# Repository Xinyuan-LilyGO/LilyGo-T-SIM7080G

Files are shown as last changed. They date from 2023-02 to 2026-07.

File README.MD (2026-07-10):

<h1 align = "center">✨ LilyGO T-SIM7080G  ✨</h1>

## **English | [中文](README_CN.MD)**

## News

- SIM7080G supports **NB-IoT** and **Cat-M** in global frequency bands, but does **not support 2G/3G/4G**. Please confirm that the SIM card used supports **NB-IoT** or **Cat-M** before use.
- The SIM card must be inserted first before starting the SIM7080. If the SIM card is inserted after the SIM7080 is turned on, the modem will not be able to detect the SIM card.

## 1️⃣ Examples preview

```
examples 
├─AllFunction                       # Full function test example
├─ATDebug                           # AT Commands Example
├─BIGIOT_Gnss_Upload                # Upload positioning coordinates to BIGIOT IOT,Timed wake-up consumes about 1.2mA
├─BLE5_extended_scan                # Official BLE5 Example
├─BLE5_multi_advertising            # Official BLE5 Example
├─BLE5_periodic_advertising         # Official BLE5 Example    
├─BLE5_periodic_sync                # Official BLE5 Example
├─MinimalCameraExample              # Example of camera use
├─MinimalDeepSleepExample           # DeepSleep example
├─MinimalLowBattPowerExample        # Low Battery example
├─MinimalModemGPSExample            # SIM7080G GPS example
├─MinimalModemNBIOTExample          # SIM7080G NBIOT example
├─MinimalModemPowerSaveMode         # SIM7080G power maintenance example
├─MinimalModemSleepMode             # SIM7080G sleep example
├─MinimalModemAndEspSleep           # SIM7080G & ESP32 sleep example
├─MinimalModemUpgrade               # Upgrade SIM7080 built-in firmware
├─MinimalPowersCurrentExample       # Example of PMU charge current debug
├─MinimalPowersExample              # Example of PMU
├─MinimalSDCardExample              # Example of using SDCard
├─ModemFileUploadExample            # File Upload Example            
├─ModemMqttPublishExample           # MQTT Publish Example            
├─ModemMqttsAuthExample             # MQTTS Authentication Example    
├─ModemMqttsExample                 # MQTTS Example    
├─ModemMqttSubscribeExample         # MQTT Subscribe Example     
├─SIM7080G-ATT-NB-IOT-AWS-MQTT      # MQTTS AWS By @bootcampiot
├─SIM7080G-ATT-NB-IOT-HTTP-HTTPS    # HTTP/HTTPS  By @bootcampiot
└─SIM7080G-ATT-NB-IOT-SSL-Mosquitto # MQTTS Mosquitto By @bootcampiot
```

## 2️⃣ Quick Start

### PlatformIO

1. Install [VisualStudioCode](https://code.visualstudio.com/) and [Python](https://www.python.org/)
2. Search for the `PlatformIO` plugin in the `VisualStudioCode` extension and install it.
3. After the installation is complete, you need to restart `VisualStudioCode`
4. After restarting `VisualStudioCode`, select `File` in the upper left corner of `VisualStudioCode` -> `Open Folder` -> select the `LilyGo-T-SIM7080G` directory
5. Click on the `platformio.ini` file, and in the `platformio` column, cancel the sample line that needs to be used, please make sure that only one line is valid
6. Click the (✔) symbol in the lower left corner to compile
7. Connect the board to the computer USB
8. Click (→) to upload firmware
9. Click (plug symbol) to monitor serial output

### ArduinoIDE

1. Install [ArduinoIDE](https://www.arduino.cc/en/software)
2. Copy all the folders in the `LilyGo-T-SIM7080G/lib` directory to `<C:\Users\UserName\Documents\Arduino\libraries>`. If there is no `libraries` directory, please create a new one. Please note that you are not copying the `lib` directory, but copying the folders in the lib directory
3. Open Arduino IDE -> Tools
- Board -> ESP32S3 Dev Module
- USB CDC On Boot -> Enable  ## Note that you need to change Enable to Disable when USB is not connected, so USB CDC will not prevent the board from starting
- CPU Frequency -> 240MHz
- USB DFU On Boot -> Disable
- Flash Mode -> QIO 80MHz
- Flash Size -> 16MB(128Mb)
- USB Firmware MSC On Boot -> Disable
- PSRAM -> OPI PSRAM
- Partition Scheme -> 16M Flash(3MB APP/9.9MB FATFS)
- USB Mode -> Hardware CDC and JTAG
- Upload Mode -> UART0/Hardware CDC
- Upload Speed -> 921600
4. Insert USB into the PC and click Upload <If the upload fails, see Tips>

### Use reference

| Product | Youtube  link | explanation | Status | 
| :---: | :---: |:---:| :----: |
| T -7080G | [Youtube link](https://www.youtube.com/watch?v=lGctqLDGHz4) | How to update the firmware of SIM7080G series products | ✅ |
| LilyGo device | [Youtube link](https://www.youtube.com/watch?v=f3BybP3L7ls) | How to enter boot mode to download the firmware | ✅ |

## 3️⃣ Tips

0. T-SIM7080 has two USB ports, the USB-C port is used to upload sketches and Serial output, and Micro-USB is used for SIM7080G firmware version upgrade
1. ⚠ SIM7080G cannot connect to cellular network and GPS positioning at the same time
2. Board integrated PMU (Power management chip), with short circuit and overload protection. By default,`PWRKEY`needs to be pressed for 6 seconds to turn off the board power supply, and press`PWRKEY`for 128 milliseconds to turn on the power supply. If you need to modify the power off pressing time, please refer to`MinimalPowersExample`
3. If the charging function is required, the`PMU` `TS Pin`detection function needs to be turned off. By default, there is no NTC sensor on the board, so the `TS Pin` detection needs to be disabled before the charging function can be used normally. If the`TS Pin`detection function is not turned off, the PMU charging indicator will flash after the battery is inserted, and charging will be disabled
4. The VSYS pin is the system path voltage of the PMU. The voltage of this pin is equal to the input voltage. The output of this pin is equal to the input voltage. If the input voltage source is USB-C, then this pin is the voltage of USB-C. If it is a battery, then this pin is the voltage of the battery.
5. The `DC5` power supply voltage can be adjusted, and the maximum output current should not exceed `1A`
6. `DC1` is the core power supply voltage, and the default output is `3.3V`. Please do not adjust the `DC1` voltage through software
7. When the sketch cannot be uploaded, please press and hold the `BOOT` button on the board, and then insert the USB. At this time, you should be able to see the port in the device manager of the computer, and then click Upload Sketch again
8. When the power supply channel of the `ESP32S3` is closed incorrectly, please insert USB, and then press and hold the `BOOT` button of the board, and then press and hold the `PWRKEY` button. At this time, the board enters the download mode, and the sketch can be uploaded normally
9. If the power supply of the board cannot be turned on when the battery is connected, please check that the mechanical switch beside the USB is turned to`ON`, and then press the board `PWR` for `2 seconds`. At this time, the board should start to work
10. The range of solar input voltage is `4.4~6V`. Please select an appropriate solar panel and set the maximum charging current as `500mA`
11. If the camera is not connected, all IO ports are available. If the camera is used, the board has only `GPIO45` and `GPIO46` is idle
12. `T-SIM7080G` uses `Octal SPI PSRAM`, so **GPIO35~GPIO37** is unavailable. Please do not use these IOs
13. ⚠ **Please understand the risks to be faced before changing the voltage of peripherals, otherwise do not try to change the voltage of cameras and other on-board devices, which may cause permanent damage**
14. ⚠ **Please do not turn off the BLDO1 power supply, otherwise ESP32S3 and SIM7080G cannot communicate normally**
15. Please check the [Operating Instructions](./docs/sim7080_update_firmware.md) for updating the built-in firmware of the modem. Generally, upgrading the firmware is not recommended
16. The board uses USB as the JTAG upload port. When printing serial port information on USB_CDC_ON_BOOT configuration needs to be turned on. 
If the port cannot be found when uploading the program or the USB has been used for other functions, the port does not appear. 
Please enter the upload mode manually. 
    1. Connect the board via the USB cable
    2. Press and hold the BOOT button , While still pressing the BOOT button, press RST
    3. Release the RST
    4. Release the BOOT button
    5. Upload sketch
17. If you encounter a problem that you cannot register a network, please refer to this [issue#100](https://github.com/Xinyuan-LilyGO/LilyGo-T-SIM7080G/issues/100#issuecomment-2662392543)
18. How to connect an external 5V circuit to the board?
    1. The SIM7080G-PMU version does not have a pre-installed 5V external pin. If you need to connect an external 5V source but don't want to use a USB-C connection, you can solder the external 5V positive terminal to the pad as shown in the diagram below.
    

## 4️⃣ Where to buy:

1. [AliExpress](https://www.aliexpress.us/item/3256805002673427.html)
2. [LilyGo Store](https://www.lilygo.cc/products/t-sim7080-s3)

## 5️⃣ Pins

| Camera | PWDN | Reset  | XCLK | SDA | SCL | VSYNC  | HREF | PCLK |
| --- | --- | --- | --- | --- | --- | --- | --- | --- |
| GPIO | N/A | 18 | 8 | 2 | 1 | 16 | 17 | 12 |
| **Camera** | **D9** | **D8** | **D7** | **D6** | **D5** | **D4** | **D3** | **D2** |
| GPIO | 9 | 10 | 11 | 13 | 21 | 48 | 47 | 14 |

* If you do not use a camera, you can freely allocate IO ports here. Assuming you need to allocate I2C, please use the display to call Wire and pass the required IO ports, such as
    ```c
    int sda = 13;  // You can also use other IO ports
    int scl = 21;  // You can also use other IO ports
    Wire.begin(sda,scl)
    ```

| Modem | PWR | RXD | TXD | RI  | DTR |
| ----- | --- | --- | --- | --- | --- |
| GPIO  | 41  | 4 | 5 | 3 | 42  |

| PMU  | SDA | SCL | IRQ |
| ---- | --- | --- | --- |
| GPIO | 15  | 7 | 6 |

| SDCard | CMD | CLK | DATA |
| --- | --- | --- | ---- |
| GPIO | 39  | 38  | 40 |

## 6️⃣ Power domain

| Modem | Camera | ESP32S3 | SDCard | Level conversion |
| --- | --- | --- | --- | --- |
| DC3/BLDO2(GPS) | ALDO1/ALDO2/ALDO4 | DC1 | ALDO3  | BLDO1 |

## 7️⃣ Voltage range

| Battery Voltage requirements | Minimum | Maximum | Charging Current |
| --- | --- | --- | --- |
| SIM7080G | 3.5V | 4.2V | Custom adjustment, maximum 1A |

* It is recommended to use flat top 18650 batteries with a capacity of more than 2500mA

| Solar Voltage requirements | Minimum | Maximum | Charging Current |
| --- | --- | --- | --- |
| SIM7080G | 4.4V | 6V | 500mA |

> \[!TIP]
>
> It is recommended to use a solar panel with an output voltage of 6V or 5V and a power of about 5-10W. Solar energy can only charge the battery. Without the battery, the panel cannot supply power.
> Please note that this is only a suggestion. It is not necessary to use a 5-10W solar panel. 1W is also acceptable.
> The size of the solar panel determines the current and speed of solar charging. Please note that depending on the environment,
> the sunshine time may not exceed one hour per day. At this time, if the solar panel is too small and the light is not sufficient, it cannot be charged.

## 8️⃣ ON-BOARD LED

| FUNCTION | COLOR |
| --- | --- |
| MODEM STATUS | RED (Near the modem) |
| MODEM NETWORK STATE | RED (Near the modem) |
| CHARGE LED | BLUE (Controlled by PMU, default charging indicator) |

* The network status light can be turned off by command, please see the AT manual `AT+CNETLIGHT` command
* Status light cannot be turned off

### **MODEM NETWORK STATE**

| Network light status | Module working status |
| --- | --- |
| 64ms on/ 800ms off | When not registered on the network |
| 64ms on/ 3000ms off  | Already registered on the network (PS domain registration successful) |
| 64ms on/ 300ms off | During data transmission (PPP dial-up state and when using internal TCP/FTP/HTTP and other data services) |
| Off | Power off or PSM sleep mode |

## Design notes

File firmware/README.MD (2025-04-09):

## 1. News

* The firmware supports any one in the list below. The firmware used in the list below is the same and there is no need to distinguish it.

## 2. How to Flash ?

### Use ESP Download Tool

- Download [Flash_download_tool](https://www.espressif.com.cn/sites/default/files/tools/flash_download_tool_3.9.7_0.zip)

web_flasher

* Note that after writing is completed, you need to press RST to reset.

### Use Web Flasher

- [ESP Web Flasher Online](https://espressif.github.io/esptool-js/)

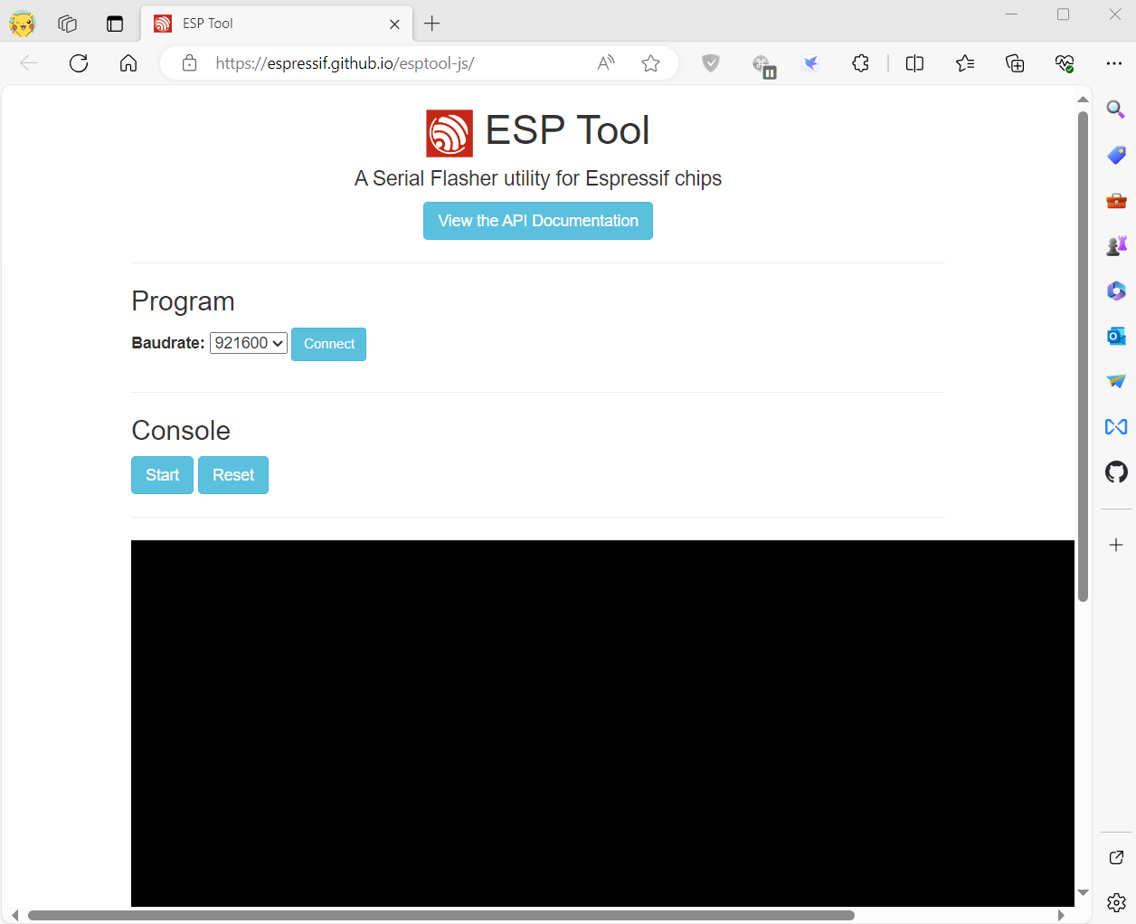
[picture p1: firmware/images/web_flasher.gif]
web_flasher


* Note that after writing is completed, you need to press RST to reset.

### Use command line

If system asks about install Developer Tools, do it.

```bash
python3 -m pip install --upgrade pip
python3 -m pip install esptool
```

In order to launch esptool.py, exec directly with this:

```bash
python3 -m esptool
```

```bash
esptool --chip esp32s3 --baud 921600 --before default_reset --after hard_reset write_flash -z --flash_mode dio --flash_freq 80m 0x0 firmware_file.bin
```

## 3. FAQ

Can't upload any sketch, please enter the upload mode manually.

1. Connect the board via the USB cable
2. Press and hold the **BOOT** button, While still pressing the **BOOT** button, **Not SBOOT**
3. Press **RST** button
4. Release the **RST** button
5. Release the **BOOT** button
6. Upload sketch
7. Press the **RST** button to exit download mode

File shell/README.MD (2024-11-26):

## A76XX-3D.stp

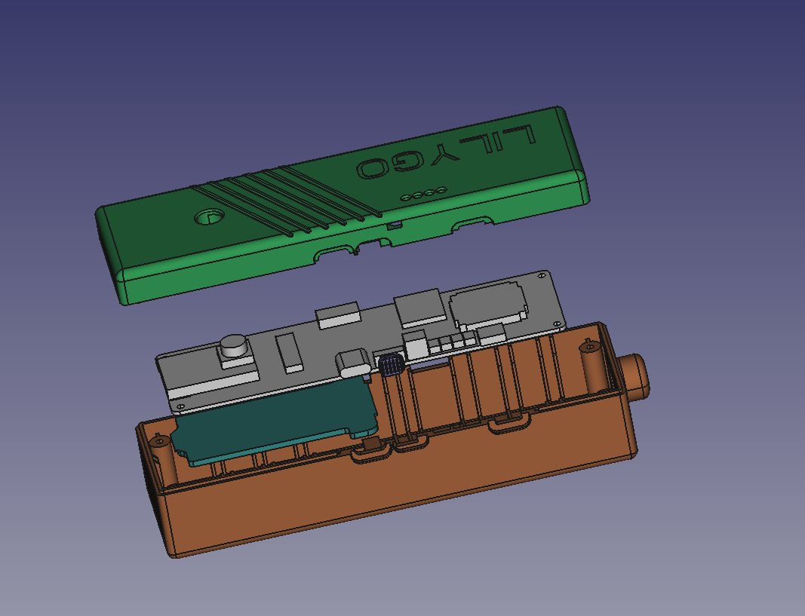
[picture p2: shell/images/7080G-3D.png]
A76XX-3D.stp


# Battery Holder

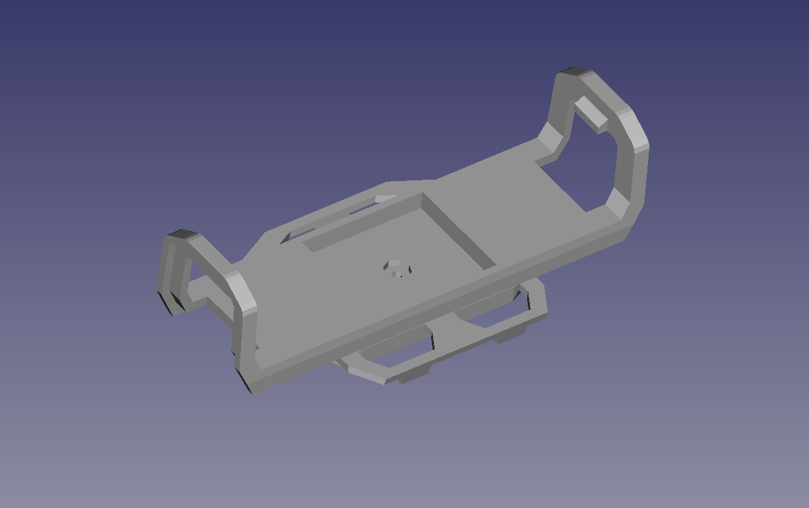
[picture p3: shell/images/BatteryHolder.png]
BatteryHolder


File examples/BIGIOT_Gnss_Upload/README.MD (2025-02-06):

[Platform link](https://www.bigiot.net)
[Relevant communication protocol of Shell IOT users](https://www.bigiot.net/help/33.html)

## Current consumption

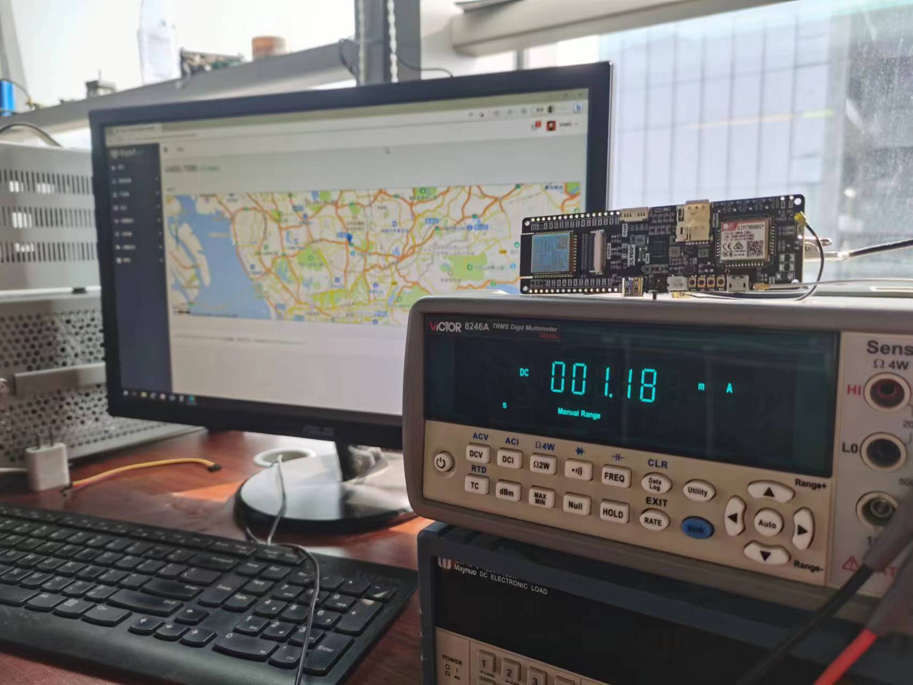
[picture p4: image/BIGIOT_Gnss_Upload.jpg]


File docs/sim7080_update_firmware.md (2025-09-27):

## Quick Step

* [SIM7080G-1951B17SIM7080](https://drive.google.com/file/d/1-m0eF53mw9n0vw4vfNZ88cRR3GM0T-a1/view?usp=sharing)

1. Update the built-in firmware of ESP32S3 using [MinimalModemUpgrade](../examples/MinimalModemUpgrade/MinimalModemUpgrade.ino) to ensure that the program is only responsible for enabling SIM7080G
2. Connect the two USB ports of the board, USB-C and Micro-USB, and operate according to the following image

3. Open [SIM7080 Driver](https://drive.google.com/file/d/1YGMAH57G7QRPPg9Vrx_PJX9Z7VdwxhIF/view?usp=sharing)
   
4. There are two ways to add drivers:

    (1)Open the computer device manager and follow the steps below to add the driver. 
    
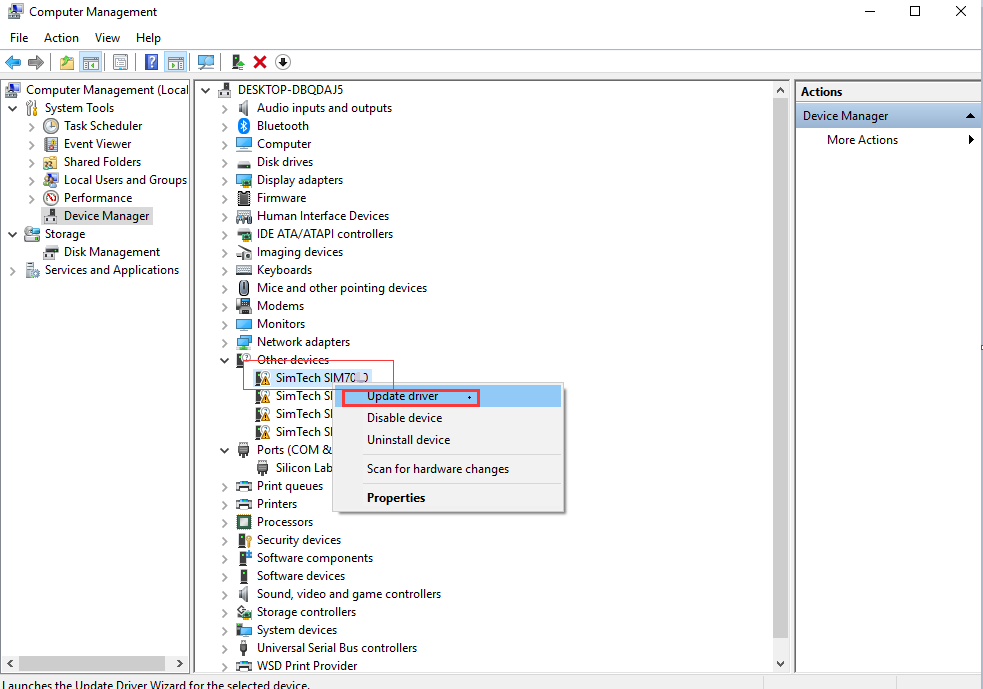
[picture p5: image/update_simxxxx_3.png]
    
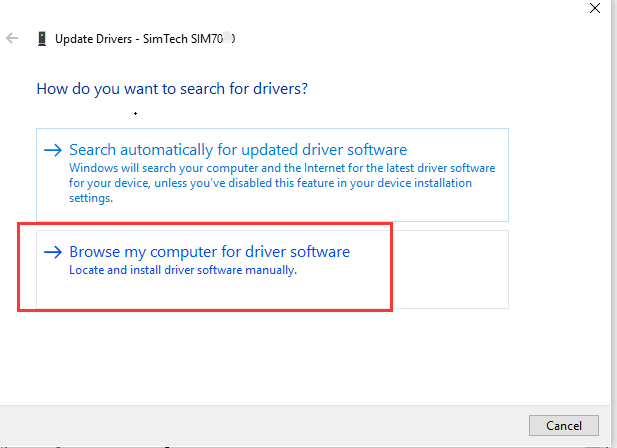
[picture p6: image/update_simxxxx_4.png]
    
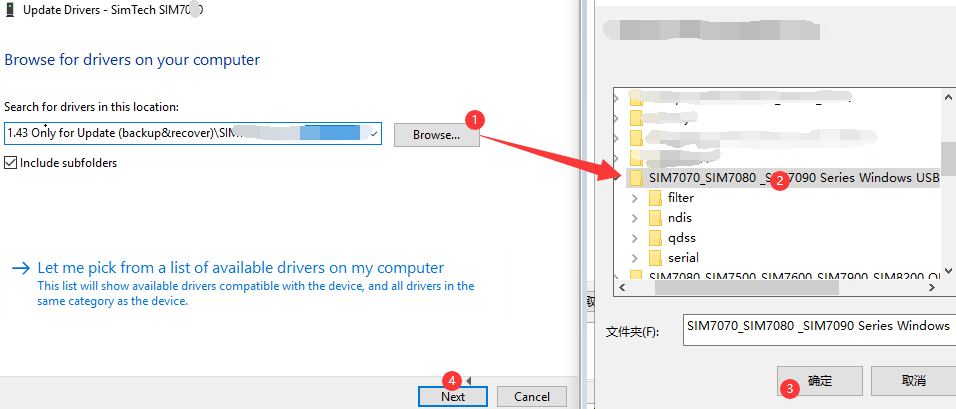
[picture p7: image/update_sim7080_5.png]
    
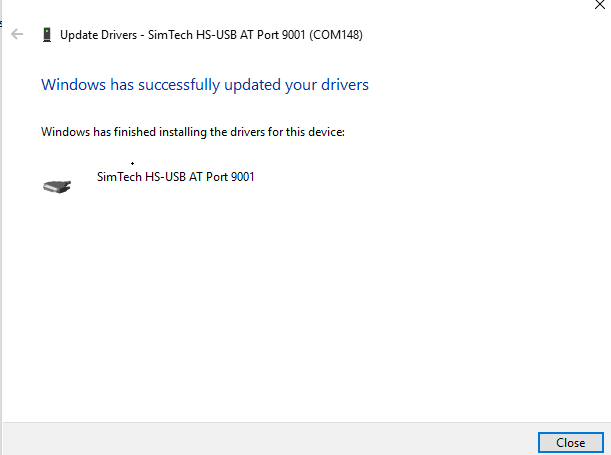
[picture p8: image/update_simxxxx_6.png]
    

    (2) Open [SIMCOM_Windows_USB_Driver](https://drive.google.com/file/d/1YGMAH57G7QRPPg9Vrx_PJX9Z7VdwxhIF/view?usp=sharing)

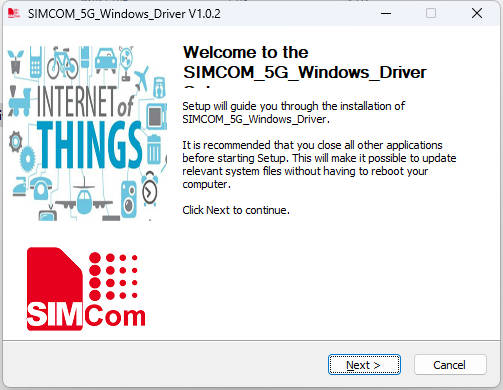
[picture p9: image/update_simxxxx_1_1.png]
    
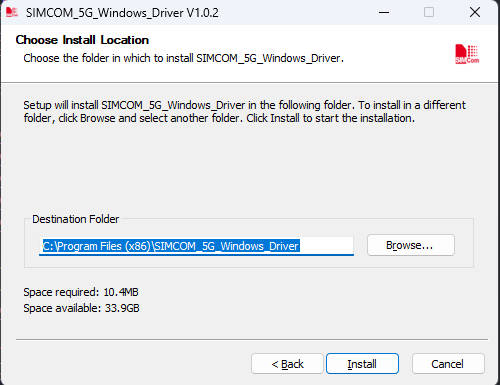
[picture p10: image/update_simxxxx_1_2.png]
    
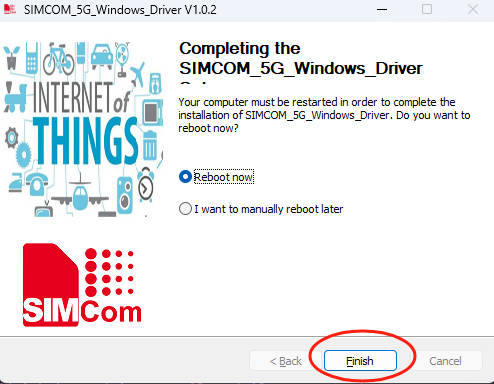
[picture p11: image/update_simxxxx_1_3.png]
    

    Follow the above steps to install the driver for the remaining ports that are not installed.
    

5. Download [upgrade_tool](https://drive.google.com/file/d/1nOqJuzBgE8KrMkpQUAWy3nJwqEBVABVn/view?usp=sharing) , The diagram is for version 1.57. The tool has been updated to 1.67. Please use the latest upgrade tool.
6. Open `sim7080_sim7500_sim7600_sim7900_sim8200 qdl v1.58 only for update.exe`
7. Open the upgrade tool and follow the diagram below 

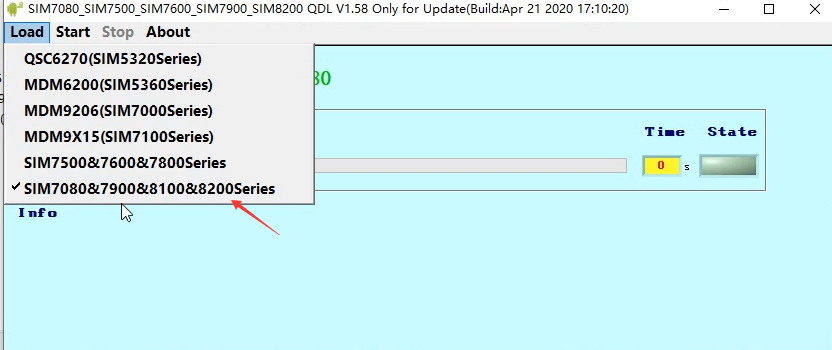
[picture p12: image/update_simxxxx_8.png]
    
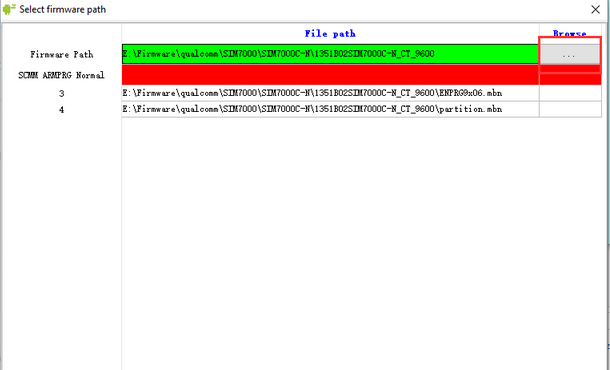
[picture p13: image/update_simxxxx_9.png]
    
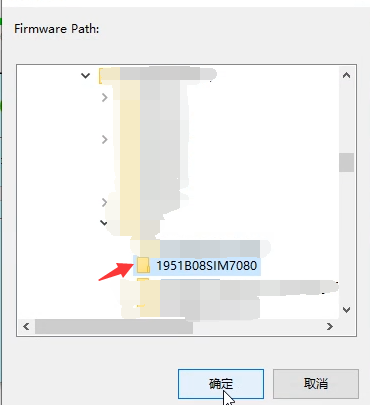
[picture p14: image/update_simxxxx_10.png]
    
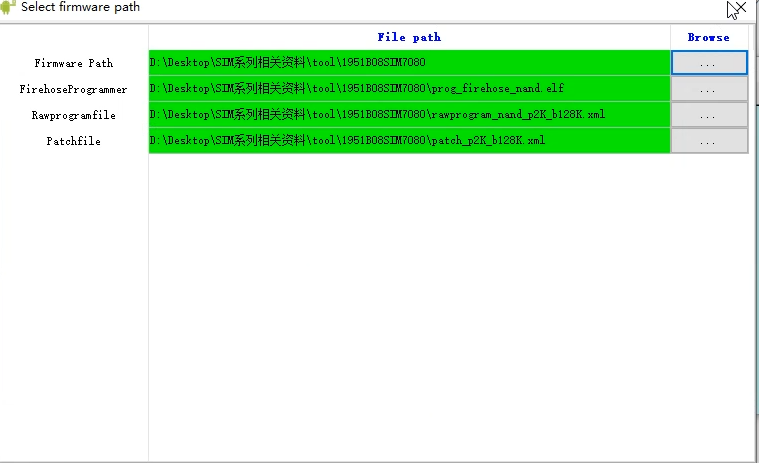
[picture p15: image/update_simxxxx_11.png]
    
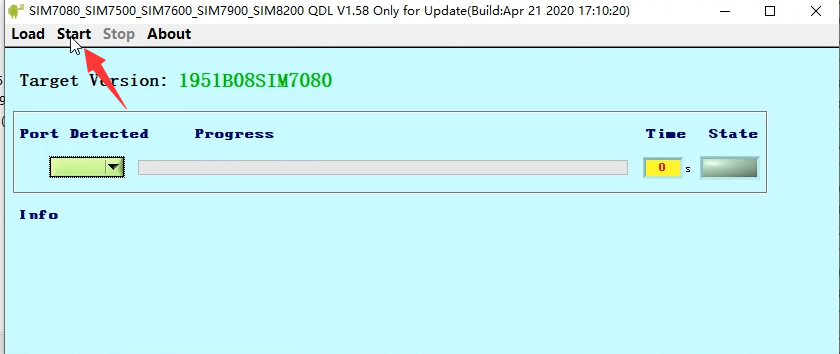
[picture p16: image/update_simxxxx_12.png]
    
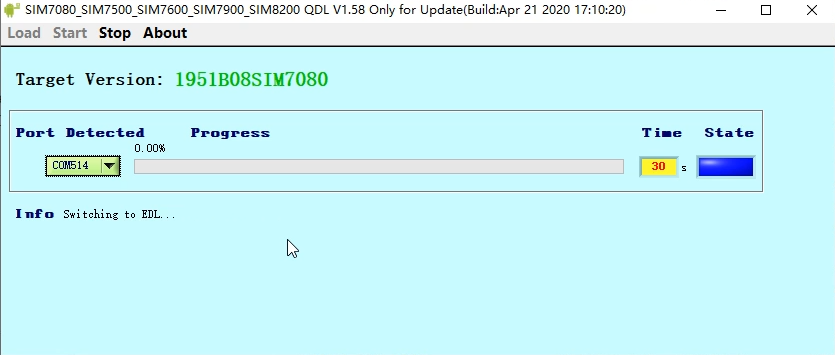
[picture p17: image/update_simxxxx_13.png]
    
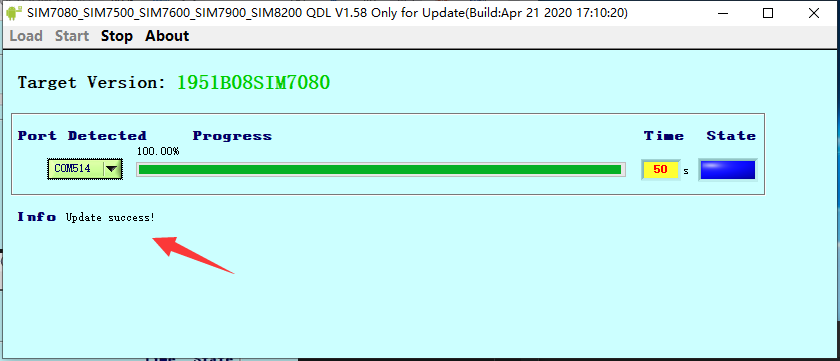
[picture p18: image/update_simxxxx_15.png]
    

8. Open the serial terminal tool, or the built-in serial tool of `Arduino IDE`, select `AT Port` for the port, and enter `AT+CGMR` to view the firmware version 


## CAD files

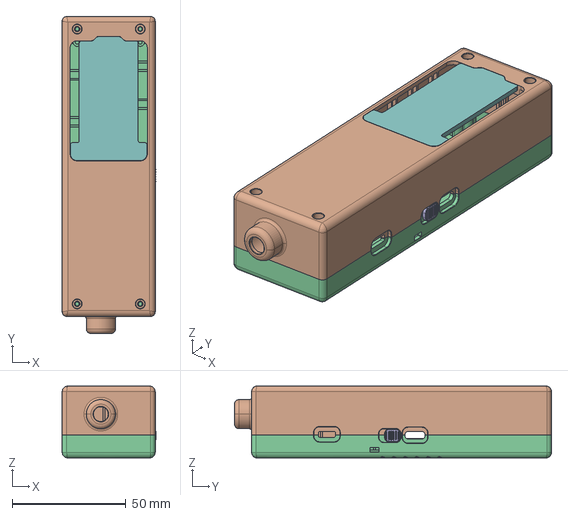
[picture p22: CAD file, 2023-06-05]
shell/0-all_asm.stp
41.1 x 139.2 x 31.6 mm

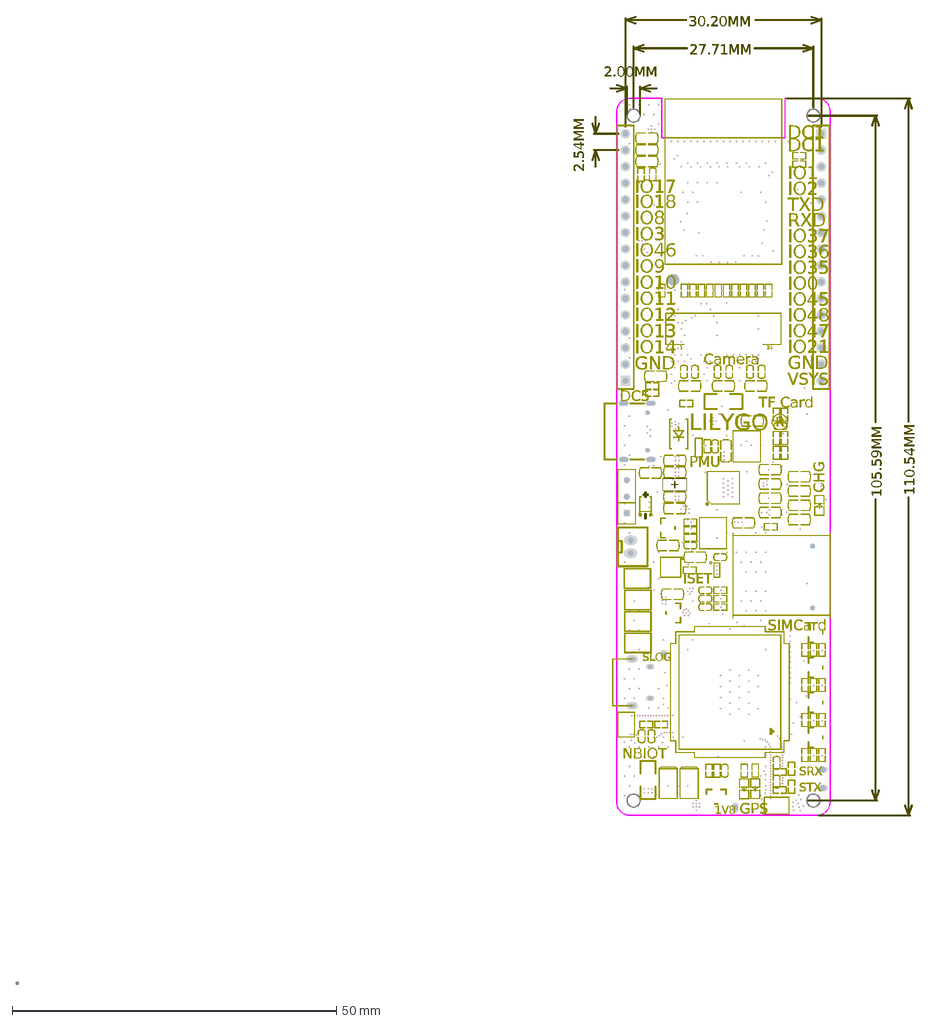
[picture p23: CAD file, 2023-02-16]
dwg/T-SIM7080G.DXF
IO45
IO8
IO2
IO12
Camera
NBIOT
IO35
IO36
TF Card
IO0
DC1
IO18
ISET
IO47
VSYS
IO10
IO21
CHG
IO14
IO37
IO3
IO11
SIMCard
IO1
GND
GPS
IO13
SRX
IO48
IO17
STX
PMU
IO9
1V8
RXD
LILYGO®
DC5
TXD
IO46
SLOG
2.54MM
27.71MM
30.20MM
2.00MM
105.59MM
110.54MM
1
24

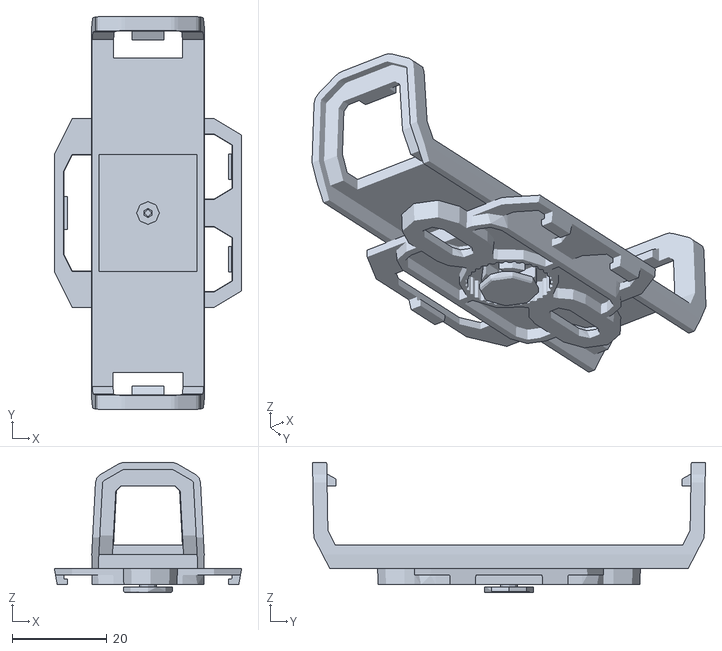
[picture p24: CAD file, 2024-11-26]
shell/BatteryHolder.stl
39.5 x 82.9 x 27.5

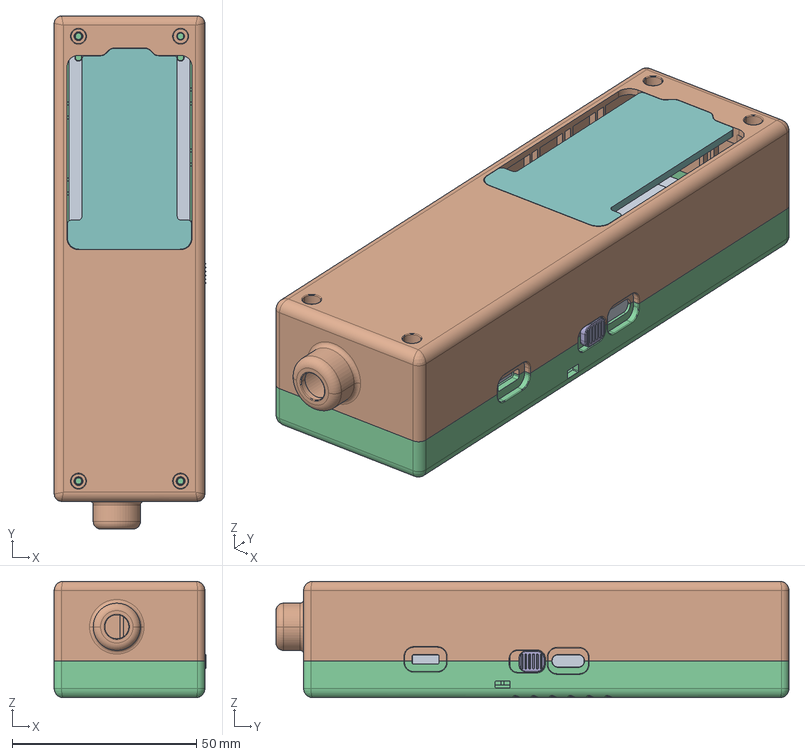
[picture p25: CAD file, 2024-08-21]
shell/A76XX-3D.stp
41.1 x 139.2 x 31.6 mm
0-PCB

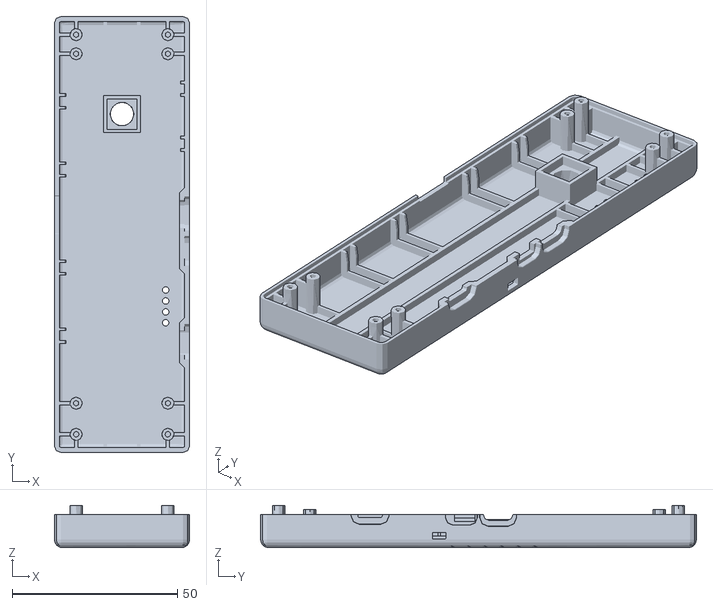
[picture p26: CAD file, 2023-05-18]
shell/0-front.stl
40.9 x 131.7 x 12.8

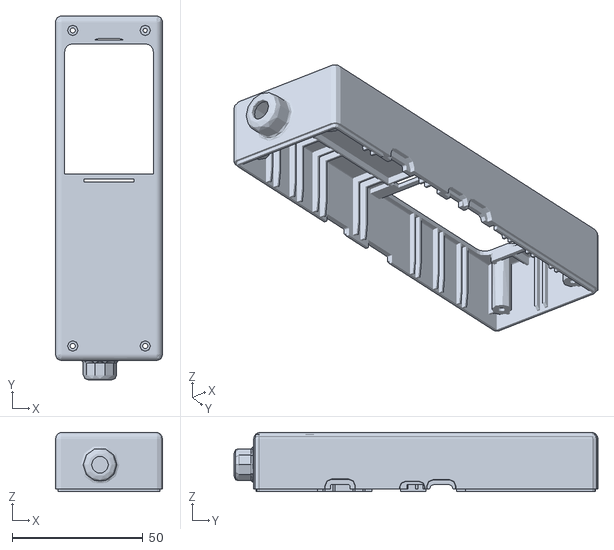
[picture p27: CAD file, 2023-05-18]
shell/0-below.stl
40.9 x 139.2 x 22.6

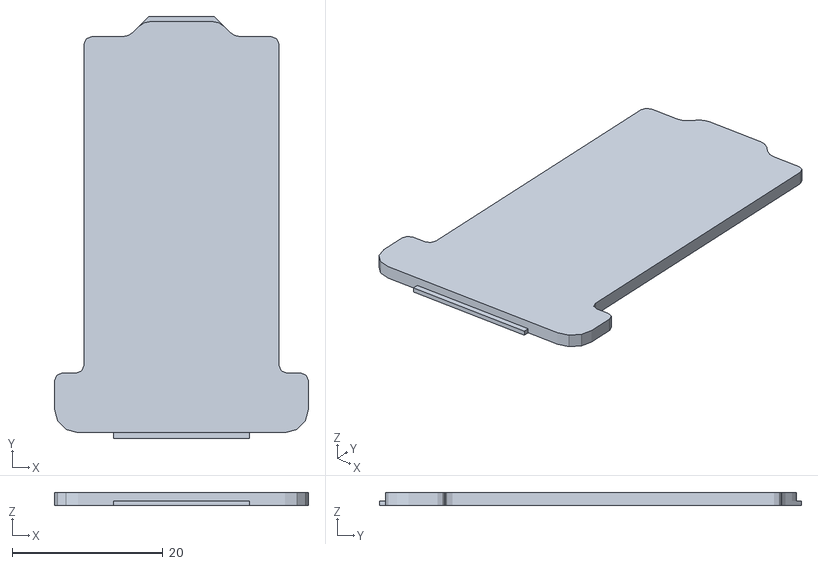
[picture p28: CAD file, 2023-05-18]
shell/0-cover.stl
33.7 x 56.0 x 1.70

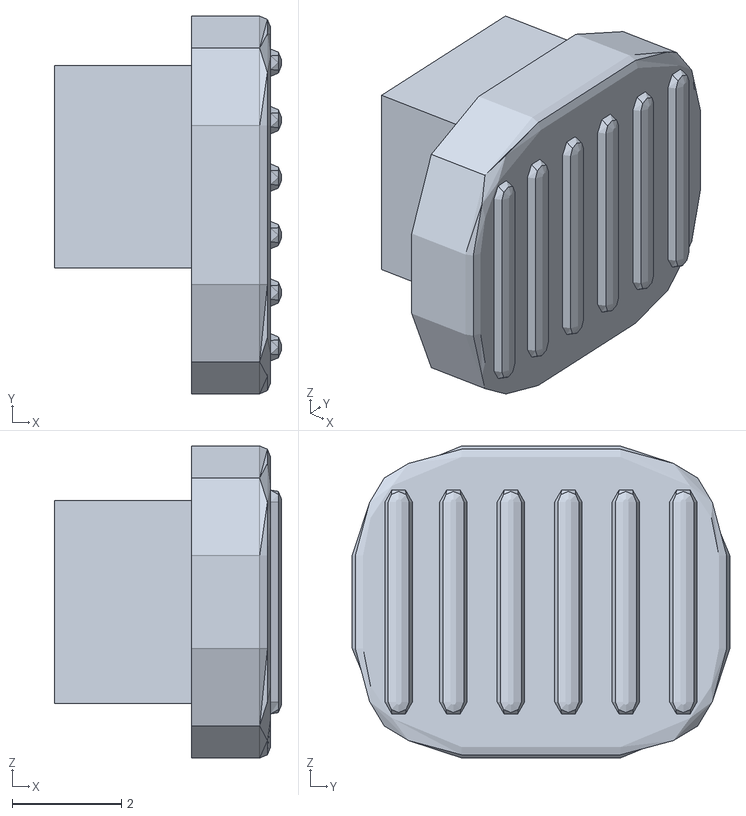
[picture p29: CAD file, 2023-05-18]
shell/0-KEY.stl
4.15 x 6.90 x 5.70

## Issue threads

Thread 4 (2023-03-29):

AWS MQTT Access

wenjun1972, 2023-03-29:
Hi, do you have examples to access AWS MQTT through the RootCA, device cert and private key ?

wenjun1972, 2023-03-31:
Hi, do you have any successful code to connect AWS MQTT? My try was failed at the last step at AT+SMSSL as below.

AT+CSSLCFG="CONVERT",2,"rootCA.crt"

OK
AT+CSSLCFG="CONVERT",1,"deviceCert.crt","devicePrivateKey.pem"

OK
AT+SMSSL=1,"rootCA.crt","deviceCert.crt"

OK
AT+SMCONN

ERROR

lewisxhe, 2023-03-31:
I uploaded a certificate writing example, but it seems that my network problem has caused me to be unable to connect. Could you help me test whether I can connect normally?

https://github.com/Xinyuan-LilyGO/LilyGo-T-SIM7080G/blob/master/examples/ModemMqttsAuthExample/ModemMqttsAuthExample.ino

lewisxhe, 2023-04-01:
Thank you for your test. I'm a bit skeptical that I can't log in through the 8884 encrypted port. I'll try using the 1883 encrypted port for the certificate login test. If there's a message, I'll update it

wenjun1972, 2023-04-01:
Got it, do you have successful case of other T-SIM product connected to AWS through SSL certificates ?

wenjun1972, 2023-04-01:
The T-SIM7080G firmware is Revision:1951B05SIM7080, is there a way to upgrade to the latest version to try this?

lewisxhe, 2023-04-03:
I have previously tried to use encryption to log in to MQTTS in the SIM7600 and A7608 modules, using the same method. Oh! By the way, SIM7080 and SIM7000 have the same architecture. I have been trying to use encrypted login on SIM7000, but it has always failed. I think this may be the reason. Regarding the latest firmware, I have a B12 firmware, and you can try it out. Recently, I have too many things to do, and I will postpone testing this later
This is the update firmware address https://1drv.ms/u/s!AmbpOqVezk5dsVv9WzIaCx8eZGit?e=XjhxgC

wenjun1972, 2023-04-03:
Please provide the firmware upgrade tools, thanks.

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

lewisxhe, 2023-04-03:
https://github.com/Xinyuan-LilyGO/LilyGo-T-SIM7080G/blob/master/docs/sim7080_update_firmware.md

wenjun1972, 2023-04-03:
Unfortunately T-SIM7080G does not show up in my windows 11, it seems only working on windows 10.

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

lewisxhe, 2023-04-03:
Did you burn [MinimalModemUpgrade](https://github.com/Xinyuan-LilyGO/LilyGo-T-SIM7080G/tree/master/examples/MinimalModemUpgrade ), and then press and hold the SBOOT button on the SIM7080G, and then insert a micro USB into the computer?"? Win11 and Win10 are the same

wenjun1972, 2023-04-03:
Had a tried but didn’t work (nothing happened) at the last step, will try to find a win10 to run the upgrade.

Understood you are busy as of now, but please make your time to explore this issue as critical since AWS access is very popular in global.

Thanks,

Jun

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

lewisxhe, 2023-04-04:
Let me clarify the upgrade process again
1. Burn MinimalModemUpgrade, disconnect USB after burning is complete
2. Press and hold the SBOOT button on the board (the first button next to MicroUSB), and insert MicroUSB
3. Keep the SBOOT button pressed, and insert the USB. At this time, you can see the QDloader 9008 (if the driver is installed) in the Device Manager. If the driver is not installed, you need to install the driver

lewisxhe, 2023-04-04:
AWS is in an inaccessible state in my country, and I will try to connect to other IoT platforms during my free time

wenjun1972, 2023-04-04:
I tried your upgrade process again on my windows 11 desktop and a windows 11 virtual machine on mac, even I installed QDloader 9008 driver,  but both didn't show up "QDloader 9008" in windows 11 device manager, but only reported additional COM3 port. I also tried another new T-SIM7080G board but saw the same issues.

wenjun1972, 2023-04-06:
Hi, I well upgraded to B12 firmware today but still had the issue of AT+SMCONN error.

lewisxhe, 2023-04-06:
I can guess it shouldn't be a version issue, and I am currently unable to determine the reason for this issue
What's annoying is that even if I can't connect, I can't see the cause of the error. I need to seek support from SIMCOM and hope they can respond positively to my question
Also, you can try taking a look at the following two libraries to see if they can be helpful to you. Currently, I have too many things to try. If there are good results, please let me know

https://github.com/OPEnSLab-OSU/SSLClient
https://github.com/govorox/SSLClient

wenjun1972, 2023-04-06:
I am highly doubtful if ATT NB-IOT network block the SSL port.

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

wenjun1972, 2023-04-06:
Had a try on "test.mosquitto.org" by my own certs and key, and saw the same error. If SSL port 8884 is blocked by ATT, how does SIM7000 and 7600 work in ATT NB-IOT with AWS and Mosquitto ?.

13:32:32:357 -> AT+CSSLCFG="CONVERT",2,"rootCA.pem"
13:32:32:458 ->
13:32:32:458 -> OK
13:32:32:458 -> AT+CSSLCFG="CONVERT",1,"deviceCert.crt","devicePrivateKey.pem"
13:32:32:559 ->
13:32:32:559 -> OK
13:32:32:559 -> AT+SMSSL=1,"rootCA.pem","deviceCert.crt"
13:32:32:565 ->
13:32:32:565 -> OK
13:32:32:566 -> Connecting to test.mosquitto.org ...
13:32:32:566 -> AT+SMCONN
13:33:32:567 -> No valid response, retrying connect ...
13:33:33:568 -> AT+SMCONN
13:34:33:569 -> No valid response, retrying connect ...
13:34:34:569 -> AT+SMCONN
13:34:36:808 ->
13:34:36:808 -> ERROR
13:34:36:808 -> Connect failed

lewisxhe, 2023-04-07:
SIM7000, you don't need to try it, because I have tried it before. I also failed.

It is no problem to connect to SIM7600 before the manual, but I use 4G. I don't know if the NB network will also block port 433.

wenjun1972, 2023-04-07:
A good news ! Just now I can access test.mosquitto.org through 8884 after correctly configure the AT&T APN  by the code - modem.sendAT("+CGDCONT=1,\"IP\",\"m2mNB16.com.attz\"");

+SMSTATE: 1

OK

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

lewisxhe, 2023-04-07:
Really ? Just set up APN?

wenjun1972, 2023-04-07:
It seems yes, but will try to access AWS today, at least it shows 8884 is not blocked by ATT.

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

lewisxhe, 2023-04-07:
Really good news, please continue to try. If you can, please submit a PR connecting AWS here. Thank you

wenjun1972, 2023-04-07:
Sure, thank you !

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

wenjun1972, 2023-04-10:
Hi, SSL to AWS IOT Core and http/https to www.mockable.io were tested successfully this weekend, I will submit a PR here soon, thanks for your support, we can close this issue now.

wenjun1972, 2023-04-13:
Hi, Lewis,

I posted the sample codes in https://github.com/bootcampiot, please let me know how to submit a PR in your example’s repository.

Thanks

Jun

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

Closed 2023-04-10.

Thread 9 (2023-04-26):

ESP32 does not come out of deep_sleep when running on battery

gfilippi, 2023-04-26:
I'm testing the LilyGo-T-SIM7080 for deep_sleep mode and it seems that there is an issue.

I'm using a simple loop

void loop()
{
    esp_sleep_enable_timer_wakeup(5 * ONESEC_USECS);
    LOG_MSGLN("Entering deep sleep\n");
    esp_deep_sleep_start();
}

1) if I power the device using the USB connector I can see the device going in deep_sleep and rebooting every 5 secs
2) if I power the device from battery I can see the first boot, then it goes in deep sleep ... but it will never come back.

it seems to me that there is some issue with the PMU not providing 3.3v when going in deep sleep and running from battery.

note: my LiPo battery is fully charged at 4.1v

EDIT: the issue shows up only if I use an instrument to measure current from the battery. If I connect the battery without ammeter in the middle everything seems to work fine.

lewisxhe, 2023-04-27:
The 7080G board's scheduled deep sleep wake-up is no problem at all. I have tested it. [Example](https://github.com/Xinyuan-LilyGO/LilyGo-T-SIM7080G/blob/9f63ab0ae8a5af524ca44d59d443ccac0469e4d5/examples/BIGIOT_Gnss_Upload/BIGIOT_Gnss_Upload. ino Timed wakeup is also used in #L110), it has been running for a while, it works fine, you can write this sketch for a simple test.
https://github.com/espressif/arduino-esp32/blob/master/libraries/ESP32/examples/DeepSleep/TimerWakeUp/TimerWakeUp.ino

Also, please remember that if you want to connect to the computer without connecting the USB, you must turn off the USB CDC enable, otherwise every time you start it will block and wait for the USB to be connected. This is in the ini It has been stated in the document, it seems that your problem is more like not turning off the USB CDC
https://github.com/Xinyuan-LilyGO/LilyGo-T-SIM7080G/blob/9f63ab0ae8a5af524ca44d59d443ccac0469e4d5/README.MD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

gfilippi, 2023-04-28:
USB CDC is disabled in my setup. I confirm the problem.

to exploit you just need to connect an ammeter between the battery and the board to measure the "deep sleep current". The moment you put the system in deep sleep .. PMU will turn down power.

I have a workaround by interconnecting a "uCurrent by EEVBlog" instrument instead of an ammeter (btw: I tested multiple ammeters ...). If I use the dedicated "uCurrent" instrument everything works as expected and I can measure currents in all the different states of powersave/sleep cycling every 5s using the timer wakeup

lewisxhe, 2023-04-28:
So I know what the reason is because you connected an ammeter in series between the PMU and the battery, causing the starting current to decrease and causing the PMU to believe that the power supply capacity is insufficient, so the PMU will not start

gfilippi, 2023-04-28:
ok, understood. So how normally do you measure the power consumption on your battery? ... I mean .. I have a solution withthe uCurrent/EEVBLog but I'm wondering how you test it in your lab. Thanks a lot for your help

lewisxhe, 2023-04-28:
We are using a digital ammeter. Here is a picture
https://github.com/Xinyuan-LilyGO/LilyGo-T-SIM7080G/tree/master/examples/BIGIOT_Gnss_Upload

gfilippi, 2023-04-28:
very nice! could you please send a picture with connections? it is not clear where you apply power and where is the ammeter inserted in series. Thanks a lot

lewisxhe, 2023-05-04:
This is a schematic diagram
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

lewisxhe, 2023-05-22:
If you still have problems, please reopen

Closed 2023-05-22.

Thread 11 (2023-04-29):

schematic and homepage GPIO mismatch

gfilippi, 2023-04-29:
Hello, I'm trying to use the GPIO46 and I believe that there is a mismatch between the schematic and the illustration of the board from the home page: https://www.lilygo.cc/products/t-sim7080-s3

could you please clarify which one is correct? it seems to me that for example pin 9 is not matching what is reported on the schematic.

lewisxhe, 2023-04-30:
oh There is an error in the pin diagram. Thank you for your feedback. Please refer to the board schematic and the silk screen on the board for details
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

gfilippi, 2023-04-30:
I verified each pin manually and it seems to me that the silkscreen is correct, while the schematic is wrong.
Could you please upload the correct schematic that matches the current board?

thanks

lewisxhe, 2023-04-30:
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
The schematic is not incorrect, and I am certain it is correct

gfilippi, 2023-04-30:
Hi lewis, on the schematic P2 is exposing CAM_D2 on pin 3 and CAM_D6 on pin 4, but D2 is IO14 and D6 is IO13.

instead on P2 we have IO17 and IO18.

please confirm

lewisxhe, 2023-04-30:
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

I understand what you mean, but the starting position of the needle arrangement is different, and the understanding is different.

lewisxhe, 2023-04-30:
In order to reduce misunderstandings, I have reversed the Pin header

Closed 2023-04-30.

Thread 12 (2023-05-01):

PWRKEY PIN

wenjun1972, 2023-05-01:
Hi,

What is the PWRKEY pin ? 7080G pinout tells GPIO41 for PWR, is it correct one?

I expect to set the PSM mode and wake up the modem by pulling LOW from HIGH, but I read the status of that PIN is always LOW.

Thanks,

Jun

wenjun1972, 2023-05-03:
Can you point to me any example code to pull low this function pin to exit from PSM status ?

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

lewisxhe, 2023-05-03:
Sorry, I misunderstood, PWRKEY exists and it is connected to IO41, you wake up from PSM mode, you need to pull down PWRKEY, there is a level conversion circuit in the hardware, so you need to set IO41 to HIGH, this When PWRKEY will be LOW

lewisxhe, 2023-05-22:
If you still have problems, please reopen

ibethcompany, 2023-05-30:
Hello, I'm using the battery and when the battery runs out or I remove the battery from the board and return it, the program does not start, I have to press the physical PWR button on the board for it to work...

Is there any way to make it so that when the battery dies or I remove it and put it back in, the program will work normally again without having to press the PWR button on the board?

Thank you very much @lewisxhe

lewisxhe, 2023-05-31:
If you need to connect the battery to automatically power on, it cannot be done on the current hardware

Another way is to modify the hardware. You need to connect the PMU_IRQ and GND in the picture below. At this time, the battery will be connected to the computer and it will automatically start up. However, the disadvantage is that the interrupt signal of the PMU cannot be used.
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

Closed 2023-05-22.

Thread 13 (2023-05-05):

LilyGo-T-SIM7080G power consumption in deep sleep

robizzar, 2023-05-05:
What about your measurement?
It is very high.

At switch-on (PMU is still off) the current drawn is already 240uA.
Pressing button PWRKEY to start my ESP32s3 firmware, which simply goes into deep sleep turning off all unused PMU outputs, the current draw increases to 1.2mA.
Thanks.

lewisxhe, 2023-05-05:
I have described the power consumption during sleep in the [README](https://github.com/Xinyuan-LilyGO/LilyGo-T-SIM7080G/blob/304a499a4cfef5fe65b671813c1606427214b95b/README.MD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), which is also 1.2mA, and I am not looking for the reason why the power consumption is so high.

Other sleep consumption using PMU is about 400uA, SIM7080 currently I do not know what is causing it

robizzar, 2023-05-05:
In your test, in deep sleep your power consumption is 1.2mA as mine.
Is it right?

What do you mean for  _sleep consumption using PMU_?  I do not understand this..

robizzar, 2023-05-05:
The other versions of LILYGO (SIM7000G and A7670E) consume much less current.
Do you think you will try to find the cause of this problem?

4ib3r, 2023-05-17:
I had the same problem, in my case lowering DC1 voltage to 2500mV before esp32 enter deep sleep (and back to on wake-up 3300mV) allowed me to decrase current consumption from battery below 0.6mA.

lewisxhe, 2023-05-22:
Because of the use of the PMU, the deep sleep current consumption will increase, which cannot be solved on the current version of the hardware.

theMladyPan, 2023-06-22:
Hi all, Can you please provide minimal example for deep sleep? I have been tinkering around but cannot go below 25mA (Ive used snippets from the examples/BIGIOT_Gnss_Upload/BIGIOT_Gnss_Upload.ino but without success. The device goes to deep sleep (Serial is terminated) and but power draw remains at 25mA. No external components attached only battery (No USB either).

hugo8873, 2024-03-12:
Hi all, I might archived an even lower power consumption, but I dont have any gadget to measure it in uA level.  You guys want to have a try and share the results? @lewisxhe @theMladyPan @robizzar

From last night 23:49, I measured a 4.132v voltage, and in this afternoon 13:53, It is 4.116v, in 14 hours, it only had 16mV drops.  Im using a small 230mAh Li-on batter.

In my void anySleepFucntion(); I did following steps:
1. modem.poweroff();
2. while (modem.testAT()) {
      Serial.println("Modem still active...");
      delay(1000);
    }
3. Disable all ADC related functions by calling:
  PMU.disableTemperatureMeasure();
  PMU.disableBattDetection();
  PMU.disableVbusVoltageMeasure();
  PMU.disableBattVoltageMeasure();
  PMU.disableSystemVoltageMeasure();
4. Turn off all DCs, LODs and CPULDO
5. end Serials and wires,
6. and eventually, reset used GPIOs in my sketch by gpio_reset_pin(GPIO_NUM_?);

Check the codes;
```
void setupSleepMode(void) {
  PMU.setChargingLedMode(XPOWERS_CHG_LED_BLINK_4HZ);
  // Turn off modem
  modem.poweroff();
  // Wait until the modem does not respond to the command, and then proceed to the next step
  while (modem.testAT()) { //double while() check
    delay(1000);
    while (modem.testAT()) {
      Serial.println("Modem still active...");
      delay(1000);
    }
  }
  Serial.println("Modem not responding. Modem turned off.");

  // Turn off ADC data monitoring to save power
  PMU.disableTemperatureMeasure();
  PMU.disableBattDetection();
  PMU.disableVbusVoltageMeasure();
  PMU.disableBattVoltageMeasure();
  PMU.disableSystemVoltageMeasure();

  // Reserve the MCU chip power supply, LilyGo AXP2101 usually uses DC as ESP power supply
  //PMU.enableDC1();

  // Turn off the power output of other channels
  PMU.disableDC2();
  PMU.disableDC3();
  PMU.disableDC4();
  PMU.disableDC5();
  Serial.println("DC turned off");
  PMU.disableALDO1();
  PMU.disableALDO2();
  PMU.disableALDO3();
  PMU.disableALDO4();
  PMU.disableBLDO1();
  PMU.disableBLDO2();
  PMU.disableCPUSLDO();
  PMU.disableDLDO1();
  PMU.disableDLDO2();
  Serial.println("A,B,C,D,LDO turned off.");

  Serial1.end();
  Serial1.end(); // Not sure why end Serial1 twice, it was copied from example
  Serial.println("Serial1 end.");

  // Clear PMU Interrupt Status Register // I applied a short press interrupt on PMU
  PMU.clearIrqStatus();
  Serial.println("PMU IRQ status cleared.");

  // Turn off the charging indicator to save power
  PMU.setChargingLedMode(XPOWERS_CHG_LED_OFF);

  Wire.end();
  Wire1.end();
  Serial.println("Wire & wire1 end");

// reset pins I used in my sketch
  gpio_reset_pin(GPIO_NUM_4);
  gpio_reset_pin(GPIO_NUM_5);
  gpio_reset_pin(GPIO_NUM_7);
  gpio_reset_pin(GPIO_NUM_15);
  gpio_reset_pin(GPIO_NUM_38);
  gpio_reset_pin(GPIO_NUM_39);
  gpio_reset_pin(GPIO_NUM_40);
  gpio_reset_pin(GPIO_NUM_41);
  gpio_reset_pin(GPIO_NUM_45);
  gpio_reset_pin(GPIO_NUM_46);
  gpio_reset_pin(GPIO_NUM_47);
  gpio_reset_pin(GPIO_NUM_48);
  Serial.println("gpio_reset_pins.");

  Serial.flush(); // copied from an example
  Serial.end();

#if !CONFIG_IDF_TARGET_ESP32S3
  Serial.println("Please implement the MCU sleep method");
#else
  // Set ESP32 to wake up externally
  //esp_sleep_enable_ext0_wakeup((gpio_num_t)pmu_irq_pin, LOW);
  esp_sleep_enable_ext0_wakeup(GPIO_NUM_6, 0);  //1 = High, 0 = Low //PMU_INPUT_PIN (6)
  Serial.println("Last step, wakeup pin defined");
  // Enable ESP32 sleep
  esp_deep_sleep_start();
#endif
}
```

manzajaro, 2024-03-21:
Hi @hugo8873

**Full execution**

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

**Function setupSleepMode execution**
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

**Sleep**
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

manzajaro, 2024-03-21:
What is the best way to sleep the device and then have the modem work? Can someone attach an example?

hugo8873, 2024-03-26:
Hi @manzajaro,
Thanks so much, happy to see the current dropped to 315uA.  I guess the essential benefit came from the reset GPIO pins.
(The 100mA while running is also shockingly large, lol)

And if you cannot restart the modem, I think the problem might lies in the PMU interrupt, I found that power supplies can behave unexpected with incontinuous MCU wire communication.  I attached a short press PMU interrupt, and it restart my peripherals normally.
Moreover, that I can think about is, if you upload a new sketch into the EPS32, it will naturally restart the chip without properly run through the power down sequence, therefore, peripherals may not initialize normally. You can use ESP.restart() in some peripheral initiation steps, and the board will eventually gets running.

You can find interrupt code from example folder and I also attach my here:
```
void setFlag(void) {
  pmu_flag = true;
}

//in setup()---
  pinMode(PMU_INPUT_PIN, INPUT_PULLUP);  // the shared pin 6 of SoC and PMU.  While DC1 power supply remained, SoC can be wakeup by this pin.  And PMU can also be forced power off by long press this pin.
  attachInterrupt(PMU_INPUT_PIN, setFlag, FALLING);
  // Close other IRQs
  PMU.disableIRQ(XPOWERS_AXP2101_ALL_IRQ);
  // Clear all interrupt flags
  PMU.clearIrqStatus();
  // Enable the required interrupt function
  PMU.enableIRQ(XPOWERS_AXP2101_PKEY_SHORT_IRQ);  //POWER KEY
```
Hope this helps.

hugo8873, 2024-03-27:
Dear @manzajaro ,
Good to hear from you again, and I found comments from example codes written like these,
```
  //! Do not turn off BLDO1, which controls the 3.3V power supply for level conversion.
  //! If it is turned off, it will not be able to communicate with the modem normally
  PMU.setBLDO1Voltage(3300);  //Set the power supply for level conversion to 3300mV
  PMU.enableBLDO1();
```
I enabled BLOD1 before DC3(modem), looks fine so far.

gtom84, 2025-01-08:
For anyone looking to further decrease deep sleep consumption, all of the above is great and in addition

from https://github.com/lewisxhe/XPowersLib/blob/master/examples/AXP2101_Sleep_Example/AXP2101_Sleep_Example.ino

> In the experiment on T-SIM7080-ESP32, the power consumption is about 900uA after setting the PMU to sleep, and 1mA if it is not set to sleep. After setting the PMU to sleep, it can save about 100uA consumption current

```
// Enable PMU sleep
power.enableSleep();

// Send IRQ wakeup command
power.enableWakeup();

```

KatmanCode, 2025-07-15:
@manzajaro Hi Friend,

Thanks for your suggestion can make my code down to 0.38mA, but I have observed the standby current could raise from 0.38mA to 1.8mA, a details description has been opened in issue #152, i would like to know if you have observed similar raise of current, or only my hardware or software problem.

Thanks for everything

Closed 2024-05-11.

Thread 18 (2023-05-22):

Wake up esp from modem after exiting PSM

4ib3r, 2023-05-22:
Hello, I try to use PSM mode and wake-up esp using RI pin (gpio 03 in esp). Unfortunately signal from a modem come randomly. Modem wakes up from PSM and status led turn on regulary.
How to properly wake up the esp from the modem after exiting PSM mode?
My modem configuration:
```
AT+CFGRI=1
AT+CURCCFG="QUALCOMM",1
AT+CURCCFG="SMS",1
AT+CURCCFG="SYS",1
AT+CURCCFG="TCPIP",0
AT+CURCCFG="NETWORK",0
AT+CPSMSTATUS=1
AT+CPSMS=1,,,"10100010","00000011"
```

lewisxhe, 2023-05-27:
PSM mode The wake-up time needs to be confirmed with the operator

4ib3r, 2023-05-29:
PSM mode and timers are working, modem wake-up in time and status led turn on after this event, when esp is not in depth sleep mode, RI pin change state regularly, but when I turn on depth sleep in esp and set `esp_sleep_enable_ext0_wakeup(GPIO_NUM_3, 0);` to this pin it not working, and pin don't change state.

lewisxhe, 2023-05-30:
Use `esp_sleep_enable_ext1_wakeup(GPIO_NUM_3,LOW)`

4ib3r, 2023-06-09:
I found the problem. The transitor based level converter for the RI pin gets 1.8V from the vdd_ext modem pin and this voltage is missing when the modem goes into PSM mode. When the modem wakes up the RI and vdd_ext drop to 1.8V at the same time but nothing changes in this case for esp32 on GPIO 3.

Closed 2023-05-27.

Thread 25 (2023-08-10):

GPS example not working properly

gfilippi, 2023-08-10:
I'm using the T-SIM7080G board with nothig attached  to the external gpio, only the board itself with the usbc cable.

I'm testing the tiny gsm example "as is" (fixed the define for the PMU which was changed recently)

I'm facing the same issue described here:
https://github.com/Xinyuan-LilyGO/LilyGO-T-SIM7000G/issues/98

===
In my case (7080, example from this repo as-is)

1) I'm in open air
2) I run the example once and I got almost immediate GPS link (!)
3) reset the board .. does not get a link anymore.
:-(

I've re-flashed the board with the same example code a couple of times ... but nothing.

The code seems to loop forever searching on the "AT+CGNSINF".

===
any idea how to debug this?
is there anything written permanently in the simcom device which stops the GPS for finding the link the second time we run the example?

===
was the example tested with the current mainline?

lewisxhe, 2023-11-04:
Really? We did not add the COLD/WARM/HOT startup command in the test, but it was correctly located. Have you sent other commands to change the settings?

lewisxhe, 2024-01-19:
If you have other questions, please reopen

Closed 2024-01-19.

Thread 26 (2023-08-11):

please clarify 24/7 operation with solar and PMU

gfilippi, 2023-08-11:
It is not clear to me how the device can sustain 24.7 (i.e. continuous) working conditions using the batter and a solar panel.

If I understand correctly the behavior of the PMU if we enter the condition where there is no sun for a long time and the battery goes to the minimum level the device will shut down.

at this point how do we return to functionality ?

- the PMU will not turn ON if we do not press the BOOT button
- the battery is not charging if the PMU is not turned ON
- if the battery is low ... none of the above will work.

===
Suppose this is a remote sensor .. how do we guarantee that the device will turn ON when the sun comes back?

what am I missing?
:-)

gfilippi, 2023-08-12:
I did study the datasheet of the PMU and looked at the schematics of the board.

It seems to me that the solar panel (VSOLAR) is used ONLY to charge the battery (page 5 of the schematics) and that we have a fet to override charging when there is VBUS connected.

As I understand it .. this confirms the issue: if the battery goes on depletion at night ... the solar panel will charge the battery the day after .. but the board will NEVER turn on by itself even if the battery is fully charged because we need to press the PWRON button on the PMU.

how to solve this problem to allow for a 24/7 operational behavior of the device??

also .. why do we need the CN3065 ? it seems to me that the AXP2101 pmu is capable of charging the battery, isn't it?
If this is true... why not using the VSOLAR as an alternative to the VBUS itself (with a proper 5V regulator on VSOLAR of course..)

please help

lewisxhe, 2023-08-12:
The PMU cannot be automatically turned on at present, you can only handle it through software.
For example, you should check whether the voltage is lower than the normal working voltage value at intervals, if it is lower, then set the esp32 to sleep state, and use the timing wake-up function to check the voltage state at intervals to see if it can work normally.

VSOLAR will charge the battery regardless of whether the PMU is powered on or not.

PMU cannot directly use solar energy for charging with high efficiency. Use CN3065 is this chip has automatic boost converter, it is the best choice for solar charging

gfilippi, 2023-08-17:
ok, understood.

but still .. even if we sleep the battery will discharge .. and in a very long (with no sun) we will enter a situation where the board will not boot anymore even if the battery is charged when the sun comes back.

what am I missing?

gfilippi, 2023-08-20:
Hi,
we have clarified that CN3065 will always charge the battery, and from the schematic this is happening from both Vsolar and VBus.

so what is the need of setting PMU charging limits (see the minmal pmu example) if the pmu is not involved in controlling the battery?

is this mandatory for a correct behavior or just a test of the API?

lewisxhe, 2023-08-20:
1. When the battery voltage drops below 3.4V, the PMU will switch to the shutdown state, and it cannot restart automatically at this time. This is the limitation of the PMU. If you need to restart the power, you must manually press the PWR button.

2. Set charging limit only set USB charging, solar charging is controlled by CN3065, can not be programmed, this is not mandatory, just for demonstration

lewisxhe, 2024-01-19:
If you have other questions, please reopen

Closed 2024-01-19.

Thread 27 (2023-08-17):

issue on PMU ADC on/off after XPowers library update

gfilippi, 2023-08-17:
There was an update to the XPowers library in commit :
[Update XPowersLib](https://github.com/Xinyuan-LilyGO/LilyGo-T-SIM7080G/commit/25fb93c3b6bf04fbc0440a493bd91e6b632c1281)

before this update I was used to measure the battery level in my loop by turning on/off "manually" the ADC with the calls:
    // Enable internal ADC detection
    PMU.enableBattDetection();
    PMU.enableVbusVoltageMeasure();
    PMU.enableBattVoltageMeasure();
    PMU.enableSystemVoltageMeasure();

and the counter part:
    PMU.disableBattDetection();
    PMU.disableVbusVoltageMeasure();
    PMU.disableBattVoltageMeasure();
    PMU.disableSystemVoltageMeasure();

Basically I was turning on ADC, do the measure, turn off ADC, like this:

loop()
{
    (...)
    pmuSetAdcON();
    vbat = PMU.getBattVoltage();
    vbus = PMU.getVbusVoltage();
    pmuSetAdcOFF();
    (...)
}

===
ISSUE: after the library update this does not work anymore.
It work correctly the very first time in the loop, but all the next probe event (in the same loop) are always reporting the same meaure .. not updating with the correct values.

This was working just fine before the update ..

any idea about fixing this use case?

thanks

gfilippi, 2023-08-17:
another issue related to this:
I'm not using the camera connector and so I'm using ALDO1 as power source for an external MAX31850K to read a thermocouple. (ALD01 is set to 3.3v in my case)

If I keep the PMU measure enabled I do get a very "unstable" reading from the MAX31850K sensor.

If I disable the PMU measures ... the reading of the sensor is super precise (!)

it seems like the pmu reading ADC is affecting the output voltages on the LDO.

but if this is the case ... we need a way to turn them off/on programmatically.

please help .. I'm running out of ideas since this was all working fine before the library update.

lewisxhe, 2023-08-18:
1. After closing, the read value is still the last recorded value, and the PMU will not refresh the data register.

2. Updating XPowersLib did not change any ADC related parts, you can check the commit information

3. Reading the ADC will not affect the voltage of the LDO, which I have checked with an oscilloscope.

gfilippi, 2023-08-18:
thanks a lot for your reply!

I will debug more .. but may I ask you to provide an example where we "open/measure/print voltage/close" in a loop each second or so? I want to make sure I'm not doing anything wrong.

lewisxhe, 2023-08-18:
Did you see if [this](https://github.com/lewisxhe/XPowersLib/blob/master/examples/AXP2101_ADC_Example/AXP2101_ADC_Example.ino) helps you?

gfilippi, 2023-08-18:
this is a good reference, thanks a lot. I've already identified one issue on my side related to the max31850 connection (parasidic power) and I'm now checking again if adc on/off is making a difference. I will report back as soon as I have a clear understanding of my problem (because I'm sure the problem is on my side...)

thanks  a lot for your help!

gfilippi, 2023-08-19:
one favor while I'm trying to debug this issue using MAX31850 for reading temperatures .... could you please confirm that GPIO45 is "free" for the user? I'm using GPIO45 as a data line for the one-wire protocol of the sensor ... just want to make sure I'm not going to interfere with something else (checking the schematic seems free to me...)

thanks

lewisxhe, 2023-08-21:
single bus? Please do not use GPIO40 or above, please replace it with GPIO22 or below IO, I remember that GPIO above GPIO22 will have problems with single bus

gfilippi, 2023-08-21:
ouch...  yes I'm using MAX31850 which is one-wire protocol (I suppose you call it single bus..)

so ... If I'm not using the camera all the GPIO9-GPIO14 (exposed on the left side of the board) can be used for this sensor, correct? (meaning one pin in that group)

lewisxhe, 2023-08-21:
Yes, try to use GPIO below GPIO22

gfilippi, 2023-08-22:
so the issue of "wrong temperature" came out again towards end of the battery life (3.76v) ... which let me thinking ...

I'm using ALDO2 to power the MAX31850 sensor .. but I set the ALDO2 to 3.3v ... do you know the minimum "voltage drop" for the LDOs of the AXP2101? I'm looking at the datasheet but I can't find it ... I might have to measure this before moving GPIO

gfilippi, 2023-08-30:
hello,
after few days of logging I can say that the issue is related to the MAX31850 itself. The sensor is sensitive to EMI and I was not powering off the modem while taking the temperature measurements. Now I make sure to power of both wifi/BT and simcom modem 1s before taking the temperature measure and every single value is correct (tested for a long, long time).

gfilippi, 2023-08-30:
issue was not related to the pmu or lilygo library

Closed 2023-08-30.

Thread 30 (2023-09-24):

No external power supply possible

Klabbob, 2023-09-24:
Am I correct in the assumption that it is not possible to power the board with an external power supply other than the USB port? There is no pin assigned to VBUS on the header and DC1, DC5 and VSYS pins are only outputs, rights?

lewisxhe, 2023-11-04:
If you are sure you don't need to use the USB input, you can use the 5V input from VSYS, but you cannot connect a battery.

Klabbob, 2023-11-05:
If I connect 5V to VSYS, the board will not turn on and you als write in your tips, that it is only an output, not an input. How can I power the board through the pin header?

> 3. The board VSYS is the internal 5V boost output of the PMU, which can only be output but not input. Please do not connect an external power supply load greater than 500mA

lewisxhe, 2024-01-19:
Has this issue been resolved?

Klabbob, 2024-01-19:
No, please read the last message from me.

VSYS is only an output, not an input --> you can not power the board by connecting a external power supply to VSYS. I have also tested this to verify it.

Can you confirm that it is **not** possible to power the board with an external power source trough the header? Only USB C and the Battery Connector can be used, correct?

lewisxhe, 2024-01-19:
You can access the 5V input from here, which is the 5V access point for USBC.

VSYS is the battery path output terminal. You can use it as an input or as an output. The voltage of VSYS depends on your input voltage. You can also directly connect 5V from VSYS, but this means there will be no Automatic switching function, and cannot be connected to power from battery or USBC
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

Peer77, 2024-03-28:
I can confirm, that connecting 5V to the pad with the red arrow powers up the board and charging is working. It would be great to have a dedicated pin on the pinheader, as it is not ideal to solder direct at the diode.

Closed 2024-05-12.

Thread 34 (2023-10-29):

simcom 7080 link quality variance from board to board

gfilippi, 2023-10-29:
I have a batch of 6 board where 4 are working fine and 2 of them are having issues to connect to the network.

when they connect ... I see a poor signal (AT+CSQ is reporting 19,99 which means belo -100dBm ... very low signal)
the other boards (in the same spot of my room, using the exact same antenna from the lilygo kit) work fine with a signal of about -70dBm

I tried to swap the antenna with one of a working board but the result is the same, very poor signal.

==
I do not see anything special on the schematic (just to 0-ohm resistor to the uFL connector) and the PCB seems done very well to me, with a proper shielding on the RF antenna connection.

1) is this an issue on the SIMCOM firmware?
 2) is there anyone seeing the same variability of RF signal from board to board ?

gfilippi, 2023-10-29:
I take it back: CSQ=99 means about -70dBm .. like for the other boards.

so I have no clue why these two modules take forever to get registered on the network in comparison to the other four. I need to wait for MINUTES while for the other boards in 20-30sec I do have link.
:-(

lewisxhe, 2023-11-04:
Try sending `AT+SIMCOMATI` to see if the returned software version is consistent, and see if it is due to differences in software versions.

gfilippi, 2023-11-17:
hello, after debugging the issue was related to the list of channles to scan (which was including ALL the possible channels). I reduced the list to the one supported locally and now it seems a lot more stable

gfilippi, 2023-11-17:
not a bug

Closed 2023-11-17.

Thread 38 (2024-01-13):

LilyGo-T-SIM7080G won't turn-on with battery only

xfiber, 2024-01-13:
Dear community,

I am facing an issue with LilyGo-T-SIM7080G when connected to battery as only power source.
When battery is connected I am not able to turn-on the board.
I've tried ready this:

_"If the power supply of the board cannot be turned on when the battery is connected, please check that the mechanical switch beside the USB is turned to ON, and then press the board PWR for 2 seconds. At this time, the board should start to work"._

This does not help at all. Board does not want to turn on.

However, whenever I turn-on the board using USB-C power, and later unplug power from USB-C, board will stay on using battery power source. Whenever I turn off the board and try to start with only battery source connected, board will not turn-on. I always need to "jump start" using usb-c power.

I would appreciate your support.
Thank you.

lewisxhe, 2024-01-15:
It looks like USB CDC is blocked from starting. Try setting USB CDC ON BOOT = DISABLE
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

mathieucarbou, 2024-01-17:
@lewisxhe : what is this interface? I am starting a project with these boards and I will have the same need. Thanks:-)

mathieucarbou, 2024-01-17:
> @lewisxhe : what is this interface? I am starting a project with these boards and I will have the same need. Thanks:-)

Looking at the read me, this is Arduino IDE? Do we have some equivalent flags to pass to the compiler when we use platformio?

Thanks!

lewisxhe, 2024-01-18:
@mathieucarbou  I already have a note in the platformio.ini file
https://github.com/Xinyuan-LilyGO/LilyGo-T-SIM7080G/blob/07233c2de91e3ee80e98b61416066ef2e677465b/platformio.ini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

xfiber, 2024-01-18:
> It looks like USB CDC is blocked from starting. Try setting USB CDC ON BOOT = DISABLE ![image](https://private-user-images.githubusercontent.com/22990954/296662897-22152abd-7f7f-48d4-b3bc-7f3e7a1b9b5b.png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)

Thank you! this solved the issue.
However, when this is set as above I am not able to monitor serial port. Is this correct behaviour ?

xfiber, 2024-01-18:
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

Correct. Framework is Arduino IDE.

lewisxhe, 2024-01-19:
CDC controls whether to use USBC as print output. If set to Disable, the default Serial output will be directed to GPIO43, GPIO44. This is the QWIIC interface near the SIM7080 battery holder.

Closed 2024-04-30.

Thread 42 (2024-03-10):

EnableGPS failed after sending AT command

tuando90, 2024-03-10:
Hi Team,

I am facing an issue with `MinimalModemGPSExample.ino` example.

When trying to change GNSS accuracy to Only High Accuracy If I change to code inside `#if 0 block` into:
```c++
#if 1
    /*
    ! GNSS Work Mode Set
     <gps mode> GPS work mode.
        1 Start GPS NMEA out.
    <glo mode> GLONASS work mode.
        0 Stop GLONASS NMEA out.
        1 Start GLONASS NMEA out.
    <bd mode> BEIDOU work mode.
        0 Stop BEIDOU NMEA out.
        1 Start BEIDOU NMEA out.
    <gal mode> GALILEAN work mode.
        0 Stop GALILEAN NMEA out.
        1 Start GALILEAN NMEA out.
    <qzss mode> QZSS work mode.
        0 Stop QZSS NMEA out.
        1 Start QZSS NMEA out.*/

    //GNSS Work Mode Set GPS+BEIDOU
    modem.sendAT("+CGNSMOD=1,1,0,0,0");
    modem.waitResponse();

    /*
    GNSS Command,For more parameters, see <SIM7070_SIM7080_SIM7090 Series_AT Command Manual> 212 page.
    <minInterval> range: 1000-60000 ms
     minInterval is the minimum time interval in milliseconds that must elapse between position reports. default value is 1000.
    <minDistance> range: 0-1000
     Minimum distance in meters that must be traversed between position reports. Setting this interval to 0 will be a pure time-based tracking/batching.
    <accuracy>:
        0  Accuracy is not specified, use default.
        1  Low Accuracy for location is acceptable.
        2 Medium Accuracy for location is acceptable.
        3 Only High Accuracy for location is acceptable.
    */
    // minInterval = 1000,minDistance = 0,accuracy = 0
    modem.sendAT("+SGNSCMD=2,1000,0,3");
    modem.waitResponse();

    /*
    // Turn off GNSS.
    modem.sendAT("+SGNSCMD=0");
    modem.waitResponse();
    */

#endif
    delay(500);

    // GPS function needs to be enabled for the first use
   while(1) {
      if (modem.enableGPS() == false) {
          Serial.print("Modem enable gps function failed!!");
          delay(5000);
      } else {
        break
      }
    }
```

Then `modem.enableGPS() ` often failed. I added the code to retry to enableGPS but sometimes it works and even if it works it takes long time to wait.

Is there any suggestion to fix this problem?

Thanks in advance!

lewisxhe, 2024-03-10:
modem.enableGPS() returns false?

Did you know that the positioning function cannot be used when the SIM7080 network is turned on?

tuando90, 2024-03-13:
> modem.enableGPS() returns false?
>
> Did you know that the positioning function cannot be used when the SIM7080 network is turned on?

@lewisxhe  Yes, it returns false. I retry the enableGPS() function several times then after some time it works.
I just used GPS and BLE.
Do you have any idea?

lewisxhe, 2024-03-13:
oh ! Are you saying that after changing #if 0 to #if 1, calling modem.enableGPS() will return failure? oh ! I forgot about this. After running the SGNSCMD command, CGNSPWR will be rejected. The two commands cannot be used together. This was my mistake. I forgot to delete it. You can test it according to this application manual.

https://github.com/Xinyuan-LilyGO/LilyGo-T-SIM7080G/blob/master/datasheet/SIM7070_SIM7080_SIM7090%20Series_GNSS_Application%20Note_V1.02.pdf

tuando90, 2024-03-13:
Oh I see.
I tried what you suggested and it works well now.
Thanks @lewisxhe.

tuando90, 2024-03-13:
Hi @lewisxhe
Do you mean I should change the setup code like this?

```c++
void setup()
{

    Serial.begin(115200);

    //Start while waiting for Serial monitoring
    while (!Serial);

    delay(3000);

    Serial.println();

    // Setup BLE
    setupBLE();

    /*********************************
     *  step 1 : Initialize power chip,
     *  turn on modem and gps antenna power channel
    ***********************************/
    if (!PMU.begin(Wire, AXP2101_SLAVE_ADDRESS, I2C_SDA, I2C_SCL)) {
        Serial.println("Failed to initialize power.....");
        while (1) {
            delay(5000);
        }
    }
    //Set the working voltage of the modem, please do not modify the parameters
    PMU.setDC3Voltage(3000);    //SIM7080 Modem main power channel 2700~ 3400V
    PMU.enableDC3();

    //Modem GPS Power channel
    PMU.setBLDO2Voltage(3300);
    PMU.enableBLDO2();      //The antenna power must be turned on to use the GPS function

    // TS Pin detection must be disable, otherwise it cannot be charged
    PMU.disableTSPinMeasure();

    /*********************************
     * step 2 : start modem
    ***********************************/

    Serial1.begin(115200, SERIAL_8N1, BOARD_MODEM_RXD_PIN, BOARD_MODEM_TXD_PIN);

    pinMode(BOARD_MODEM_PWR_PIN, OUTPUT);

    digitalWrite(BOARD_MODEM_PWR_PIN, LOW);
    delay(100);
    digitalWrite(BOARD_MODEM_PWR_PIN, HIGH);
    delay(1000);
    digitalWrite(BOARD_MODEM_PWR_PIN, LOW);

    int retry = 0;
    while (!modem.testAT(1000)) {
        Serial.print(".");
        if (retry++ > 15) {
            // Pull down PWRKEY for more than 1 second according to manual requirements
            digitalWrite(BOARD_MODEM_PWR_PIN, LOW);
            delay(100);
            digitalWrite(BOARD_MODEM_PWR_PIN, HIGH);
            delay(1000);
            digitalWrite(BOARD_MODEM_PWR_PIN, LOW);
            retry = 0;
            Serial.println("Retry start modem .");
        }
    }
    Serial.println();
    Serial.print("Modem started!");

    /*********************************
     * step 3 : start modem gps function
    ***********************************/

    //  When configuring GNSS, you need to stop GPS first
    // modem.disableGPS();
    delay(500);

#if 1
    /*
    ! GNSS Work Mode Set
     <gps mode> GPS work mode.
        1 Start GPS NMEA out.
    <glo mode> GLONASS work mode.
        0 Stop GLONASS NMEA out.
        1 Start GLONASS NMEA out.
    <bd mode> BEIDOU work mode.
        0 Stop BEIDOU NMEA out.
        1 Start BEIDOU NMEA out.
    <gal mode> GALILEAN work mode.
        0 Stop GALILEAN NMEA out.
        1 Start GALILEAN NMEA out.
    <qzss mode> QZSS work mode.
        0 Stop QZSS NMEA out.
        1 Start QZSS NMEA out.*/

    //GNSS Work Mode Set GPS+BEIDOU
    modem.sendAT("+CGNSMOD=1,1,0,0,0");
    modem.waitResponse();

    /*
    GNSS Command,For more parameters, see <SIM7070_SIM7080_SIM7090 Series_AT Command Manual> 212 page.
    <minInterval> range: 1000-60000 ms
     minInterval is the minimum time interval in milliseconds that must elapse between position reports. default value is 1000.
    <minDistance> range: 0-1000
     Minimum distance in meters that must be traversed between position reports. Setting this interval to 0 will be a pure time-based tracking/batching.
    <accuracy>:
        0  Accuracy is not specified, use default.
        1  Low Accuracy for location is acceptable.
        2 Medium Accuracy for location is acceptable.
        3 Only High Accuracy for location is acceptable.
    */
    // minInterval = 1000,minDistance = 0,accuracy = 0
    modem.sendAT("+SGNSCMD=2,1000,0,0");
    modem.waitResponse();

    // Turn off GNSS.
    /*
    modem.sendAT("+SGNSCMD=0");
    modem.waitResponse();
    */
#endif
    delay(500);

    // GPS function needs to be enabled for the first use
    /*
    if (modem.enableGPS() == false) {
        Serial.print("Modem enable gps function failed!!");
        while (1) {
            delay(5000);
        }
    }
    */
}
```

lewisxhe, 2024-03-13:
Use ATDebug first, follow the instructions in the PDF linked above, and try it

Closed 2024-04-30.

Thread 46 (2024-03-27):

Power button multi usage

spatcho, 2024-03-27:
Good day,

I would like to keep using the power button on / off functionality, and also use the button to i.e. turn on an oled screen. Per example 4s press to turn off, 2s press to turn on, and short press to catch specific code. I see there is interrupt available but if my use case is possible, could I have a short code example ?

spatcho, 2024-03-28:
It worked, thank you

spatcho, 2024-03-28:
Shall I close it ?

Closed 2024-05-12.

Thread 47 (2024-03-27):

The battery has stopped working

manzajaro, 2024-03-27:
Hi, after several days of testing a code and battery life, it turns out that this morning the battery-only power supply stopped working and I don't understand why.

I'm compiling with these options!

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

I've taken measurements with the multimeter and I can see that the PMU is getting 4.1V.

I've measured all the resistors in the schematic and they give the correct value.

When I run the code connected to the usb cable it works correctly, but as soon as I remove it the device switches off.

The power button works correctly, because when it is powered by usb I press it for X seconds and the device turns off.

I run the following code [MinimalPowersExample](https://github.com/Xinyuan-LilyGO/LilyGo-T-SIM7080G/blob/master/examples/MinimalPowersExample/MinimalPowersExample.ino) to see if the PMU is OK and it returns the following result.

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

Can someone help me, thanks

lewisxhe, 2024-03-29:
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
Is the switch turned on?

manzajaro, 2024-03-29:
Hi @lewisxhe,

The button is on, the battery is on and I have been able to check that the PMU receives 4.1v from the battery.

https://github.com/Xinyuan-LilyGO/LilyGo-T-SIM7080G/assets/6926926/30cd97de-9abf-46dc-b8fc-19a7ff6d2fd1

lewisxhe, 2024-03-29:
Can you follow the instructions here and remove the diode and then run the MinimalPowersExample to see if the battery prints a connection? Now due to the presence of this diode, the battery connection will print even if the battery is not inserted.

https://github.com/Xinyuan-LilyGO/LilyGo-T-SIM7080G/issues/49

manzajaro, 2024-03-29:
> Can you follow the instructions here and remove the diode and then run the MinimalPowersExample to see if the battery prints a connection? Now due to the presence of this diode, the battery connection will print even if the battery is not inserted.

I'll do it now and tell you the result.

This is the consumption of the board, when it is switched on and the pwr button is pressed.

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

Thanks @lewisxhe

manzajaro, 2024-03-29:
Logs with the diode removed, as you can see it detects well. 1st logs without battery, then inserted and detected.

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

lewisxhe, 2024-03-30:
Can detect battery insertion and removal, but cannot use battery power?

manzajaro, 2024-03-30:
Correct, the battery alone doesn't start. You've already seen the power consumption measurements of the board.

It stopped working on its own, it was undergoing a test throughout the whole night and the next morning the board wasn't functioning and the battery was charged.

lewisxhe, 2024-04-02:
As you said, the battery path inside the AXP2101 chip may have been disconnected. Please contact your dealer for after-sales service.

Closed 2024-04-05.

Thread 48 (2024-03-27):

No ">" prompt following +CASEND after wakeup from sleep (DRX)

btuysser, 2024-03-27:
My project is based on [MinimalModemNBIOTExample](https://github.com/Xinyuan-LilyGO/LilyGo-T-SIM7080G/tree/master/examples/MinimalModemNBIOTExample). I am transmitting a ~28 byte UDP datagram every 60s and I want the modem to sleep. I am using DRX as opposed to eDRX or PSM due to future requirements.I added some UDP code (as that is not supported by TinyGSM), set +SCLKC=1 and I'm controlling DTR. The code was compiled with (-DARDUINO_USB_CDC_ON_BOOT=0) and the board is connected to a wall power supply. No UART connection.

In the setup function I acquire NB-IOT, register and open a UDP connection.

Here is my loop function and a modifed TinyGsmSim7080::modemSend :

```
 int16_t modemSend(const void* buff, size_t len, uint8_t mux) {

    while(waitResponse(5,GF(">")) != 1) {
      sendAT(GF("+CASEND="), mux, ',', (uint16_t)len);
    }

    stream.write(reinterpret_cast<const uint8_t*>(buff), len);
    stream.flush();

    // OK after posting data
    if (waitResponse() != 1) { return 0; }

    return len;
  }

void loop()
{
    static int cnt = 0;
    long t0 = millis();
    // pull DTR low in case we were sleeping
    digitalWrite(BOARD_MODEM_DTR_PIN, LOW);
    // send UDP datagram
    modem.modemSend(msg.c_str(), msg.length(), 0);
    // get to rrc idle asap
    modem.sendAT("+CRAI=1");
    modem.waitResponse(5);
    // we can go back to sleep now
    digitalWrite(BOARD_MODEM_DTR_PIN, HIGH);
    Serial.printf("\n\r--------------  SLEEP AFTER %d --------------\n\r", millis() - t0);
    delay(60000);
}
```
When I call +CASEND immediately after wakeup there is no ">" prompt in the modem serial stream. I added retries in the modemSend method and with a timeout of 5ms it takes 3 tries to get a ">" prompt. This results in an awake time of ~24ms instead of an ideal ~15ms. When increasing the waitResponse timeout to 50ms I would expect the number of tries to go down but it remains between 1 and 3 tries for an awake time of 65-117ms.

Another workaround is to add a 300ms delay after pulling DTR low but the impact on awake time is unacceptable.

Am I doing anything wrong or have others come across this issue?

Log :
```
AT+CPSI?
+CPSI: LTE NB-IOT,Online,310-260,0xF300,7573966,450,EUTRAN-BAND4,2038,0,0,-11,-98,-87,13
OK

AT+CSCLK=1
OK
AT+CACLOSE=0

AT+CACID=0
OK

AT+CAOPEN=0,0,"UDP","<IP>",<PORT>
OK

AT+CASEND=0,26
>012345678 UDP test Count 0
OK
AT+CRAI=1
OK

--------------  SLEEP AFTER 21 ms --------------
AT+CASEND=0,26
AT+CASEND=0,26
AT+CASEND=0,26
>012345678 UDP test Count 1
OK
AT+CRAI=1
OK
--------------  SLEEP AFTER 32 ms --------------
AT+CASEND=0,26
AT+CASEND=0,26
AT+CASEND=0,26
>012345678 UDP test Count 2
OK
AT+CRAI=1
OK
--------------  SLEEP AFTER 32 ms --------------
.....

```

btuysser, 2024-03-27:
Firmware Revision : 1951B12SIM7080

lewisxhe, 2024-03-29:
Are you referring to the wake-up reaction time being too long?

btuysser, 2024-03-29:
Since there is almost no information in the low power application note I hoped that the wakeup reaction time would be  be transparent to the user. After pulling DTR low I expected the modem to execute any serial command after finishing its own internal wakeup sequence.

If that is not the case then how does a user determine the **earliest** time it's safe to interact with the modem (in this case sending a UDP packet via +CASEND)?

btuysser, 2024-04-16:
Would it be possible to extend the MinimalModemSleepMode.ino example by doing multiple sleeps?

My current sequence is

- pull DTR low
- send AT commands with a timeout of 1ms until OK is received or a threshold is exceeded
- +CASEND
- pull DTR high
- .....

I just don't know if this is the optimal sequence.

Closed 2024-06-01.

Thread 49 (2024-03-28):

Set charging current limit has no effect

Peer77, 2024-03-28:
Hi Lewis!

Thank you for your good work in developing the AXP libraries. I would love to get the LilyGo SIM7080G module up and running exactly as it was possible when using the SIM800L with the AXP192

The ESP32 with SIM800 and AXP192 is showing perfect operation:

-> 100mA is set and in total ca. 180mA seen on LabPSU (must be 100mA charging current and rest accounts for the ESP to keep everything below 250mA.

But when using the same battery with the SIM7080G and also set 100mA for charging current, the drawn power is always seen as 500mA (except in the end when it is nearly charged, the drawn current drops.)

I also tried to set precharge current and termination current to 0mA -> without success.

Issue could not get resolved by switching  off unused powerlines as per below:

    Modem 2700~3400mV VDD
    PMU.setDC3Voltage(3000);
    PMU.enableDC3();

    Modem GPS Power
    PMU.setBLDO2Voltage(3300);
    PMU.enableBLDO2();

    DC1 is left untouched

    switched off unused powerlines
    PMU.disableDC2();
    PMU.disableDC4();
    PMU.disableDC5();

    PMU.disableALDO1(); // CAM
    PMU.disableALDO2(); // CAM
    PMU.disableALDO3(); // SDCARD
    PMU.disableALDO4(); // CAM
    PMU.disableBLDO1(); // ???

    PMU.disableCPUSLDO(); // ???
    PMU.disableDLDO1(); // ???
    PMU.disableDLDO2(); // ???

The current is set to be limited to 100mA via
PMU.setChargerConstantCurr(XPOWERS_AXP2101_CHG_CUR_100MA)

Confirmed via:
uint8_t val = PMU.getChargerConstantCurr();

But still the drawn current is seen as ca. 500 mA when the battery is NOT charged.
When a full charged battery is connected, the current of the entire ESP32S3 is seen at 70mA total.

Lewis, could you please confirm if the charging current in xpowers_axp2101_chg_curr_t are working for you?

Many thanks, greetings! Peer

lewisxhe, 2024-03-29:
oh ! I verified it this morning, and I found the problem that the current cannot be set. This is a hardware problem. You can remove the diode in the picture, so that the charging current will not charge from CN3065, but from AXP2101.

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

At the same time, I found a software BUG. Failure to change the register will cause the charging current setting to be incorrect.

thank you for your feedback

Peer77, 2024-04-03:
Hi Lewis,

yes, after thorough testing I can confirm your advice fixed the issues, thanks alot!

I did:

a) remove the big diode next to the USB-connector and
b) installed the XPowersLib (ver. 0.2.2)

Result:

First I have set 300mA as charging current then checked the readings.

At last I have set 100mA as charging current -> the measured current is pretty much the same as it was with the beloved AXP192 (100mA chg current + 80mA for the board)

Now after the diode has moved away from the Lilygo PCB, it is much easier to connect a small cable to the pad with the red arrow to apply 5V as charging voltage. As soon as 5V gets connected the board switches on and charges the battery. When the 5V is disconnected the board remains switched on (when battery is inserted)

To power off the board completely I use the 5V for a MOSFET to interrupt the negative pole of the 18650 battery.

If there is a future version, it would be very helpful when there is a dedicated Vin pin on the headers (replacing the VSYS pin, e.g??) If I remember that correctly, it is only possible to pickup 5V from that VSYS pin or feed 5V into the boad, but battery is not being charged by VSYS voltage.

As it is fully resolved, the issue can be closed.

Thanks again!

lewisxhe, 2024-04-29:
I will revise the later versions based on the feedback from the first version, thank you.

Peer77, 2024-04-29:
Hi Lewis,

thank you. Commit 64304d8 in combination with the removed diode works very well. Thanks for your help!

smehner1, 2024-11-20:
Hi @Peer77

can you please explain a little more how to do that? Do you have a schematic?

> To power off the board completely I use the 5V for a MOSFET to interrupt the negative pole of the 18650 battery.

Best,

Stefan

Closed 2024-04-29.

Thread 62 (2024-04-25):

LilyGo T-SIM7080G board damaged by humidity ?

mathieucarbou, 2024-04-25:
Hello,

I am testing the lilygo board outside since a few days. There is a lot of humidity outside, the lilygo is in a waterproof box (but the box has a hole for the wires on the side, so the air can enter but not the rain).

I am wondering what's this on the board ? it was not there before. It feels like the humidity stats damaging the board ?

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

The connected usb-c device is this solar panel : https://fr.aliexpress.com/item/1005005509831452.html

* Tension de fonctionnement: 5 ~ 5.5V
* Courant de travail: 0.8A ~ 1A(Max.)

lewisxhe, 2024-04-26:
Obviously it is affected by moisture. You can remove the damaged original parts first, then power on and test whether they can work.

mathieucarbou, 2024-04-26:
> Obviously it is affected by moisture. You can remove the damaged original parts first, then power on and test whether they can work.

I don't have the tools for such precise work at home. Right now, I can power the board with USB-C, solar panel connector does no work, and I can power through internal battery.

But I found that when I have a USB-C solar panel connected and internal battery, when the solar panel is not able to produce enough current, the device shuts down instead of switching to the battery.

I do not have this behaviour with the second board.

I have ordered a spray for electronic boards...

But what I don't understand is why these boards come without any varnish, silicon or resin to protect the components from humidity / moisture ?

Also, is there a solution I could do to cleanup without having to remove the components ?

How I could check if some are damaged ?

mathieucarbou, 2024-04-29:
@lewisxhe : do you know what kind of product I could use to cleanup and remove this blue-green mixture ?

Closed 2024-06-13.

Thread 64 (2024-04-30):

Bringing the board back online when re-charging a depleted 18650 battery

Peer77, 2024-04-30:
Hi Lewis,

when comparing the LilyGo SIM7080G board with the SIM800L, I observed the charging / repowering of SIM7080G is proceeding differently when the 18650 battery is discharged completely and the device went off. Please see the following scenario.

 **Behaviour of SIM800L:**

- When an empty 18650 battery is inserted (or the board discharged the 18650 until it switched off) and 5V is connected to 5V-IN pin, the battery was charging and the board came back online when the 18650 voltage was sufficient(it tried in between booting up until it succeeded)

-> Is there a way to apply this behaviour to the SIM7080G as well?

**Current behaviour of SIM7080G:**

- When an empty / depleted battery is inserted and 5V is fed to the pad (like when the power grid comes back after power interruption) of the removed diode (as mentioned in #49), it tried to boot up (but failed of course as expected). It went off and the battery was then charging normally (indicated by blue charging LED), but it charged only to 3.63V. The charging LED was then flashing at 1Hz, but the board did not come back online unfortunately. I had to remove the auxiliary
5V line (going to diode pad) and reconnect it to make it booting up again.

-> Is there a way to change that so it comes back online automatically? Or is it possible to set a higher threshold by using PMU.setLowBatShutdownThreshold() to shut down the board earlier to have sufficient power for booting up when the power grid comes back? The battery I used for this test was discharged by the board to 2.4V.

Many thanks! and best regards,

Peer

lewisxhe, 2024-05-02:
If it is lower than the PMU operating voltage, the PMU must be turned on manually. You can set the low voltage alarm to trigger the PMU interrupt to shut down in advance or enter sleep mode to save power. I have uploaded a simple test example, I hope it will be helpful to you.

Peer77, 2024-05-13:
Hi Lewis,
thank you very much, I will check and report back...

Peer77, 2024-05-24:
Hi Lewis,

thank you for the example code. Your code brought some inspiration. So I have written a small function to simply check against the return value of PMU.isVbusIn(). If powergrid goes down it returns false, and after a 1 minute I then call PMU.shutdown();. Feeding back the PSU / 5V to the pad where the diode was mounted, the device comes back online as normal. Works fine! Just to confirm, the board is really switched off after calling PMU.shutdown(), right?

Thanks!

Peer77, 2024-06-04:
Resolved, closing.

Closed 2024-06-04.

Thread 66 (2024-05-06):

using modem on one core, and another I2C device on another

Bfreak, 2024-05-06:
Hi. I am trying to run an MQTT script on one core, and read data from another i2c device on the other core, using freertos to do so.

When I try to do this, I get 'failed to initialize power' from the modem.

The MQTT tasks has default code:
```
void MQTT_task_setup(void *pvParameters) {

    Serial.begin(115200);

    //Start while waiting for Serial monitoring
    while (!Serial);

    vTaskDelay(3000);

    Serial.println();

    if (!PMU.begin(Wire, AXP2101_SLAVE_ADDRESS, I2C_SDA, I2C_SCL)) {
        Serial.println("Failed to initialize power.....");
        while (1) {
            vTaskDelay(5000);
        }
    }
```

and the other i2c has code

```
void hall_task_setup(void *Parameter) {
  Serial.println("Starting Hall_get setup");

  Wire.begin(13, 21);

  if (! sensor.begin_I2C()) {
  //if (! sensor.begin_SPI(MLX90393_CS)) {  // hardware SPI mode
    Serial.println("No sensor found ... check your wiring?");
    while (1) { vTaskDelay(10); }
  }
  Serial.println("Found a MLX90393 sensor");
```

Both can run independantly using freertos. Any suggestions? Thanks.

lewisxhe, 2024-05-07:
There is only one Wire. You initialized it twice. Of course it cannot run. You need to change one to Wire1.

lewisxhe, 2024-05-07:
According to the question you raised, https://github.com/Xinyuan-LilyGO/LilyGo-T-SIM7080G/issues/65, you directly pass the PMU initialization to Wire1, so that your sensors will not conflict

Bfreak, 2024-05-07:
thanks @lewisxhe but I have a new problem: I currently can only upload script when I connect via usb holding boot button , but get nothing in terminal. When I try and connect without boot I get either `*** [upload] Error 1` or `error 13: could not open port` when I try and open any connection. Any suggestion?

Closed 2024-06-23.

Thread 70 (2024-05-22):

UART communication

manzajaro, 2024-05-22:
Hi, I'm testing the UART communication between this device and an arduino, but I can't get it to work.

On the pin diagram it says TXD and RXD are numbers 43 and 44. but I can't get it to work, can you help me?

```
void setup() {
  Serial.begin(115200);
  while (!Serial);

  Serial1.begin(9600, SERIAL_8N1, GPIO_NUM_43, GPIO_NUM_44);

  delay(1500);

  String message = "";
  long timeCheck = millis();

  while (message.equals("") && (millis() - timeCheck) < 5000) {
    if (Serial1.available() > 0) {  // Verifica si hay datos disponibles para leer
      message = Serial1.readString();  // Lee el mensaje recibido
      Serial.print("Mensaje recibido: ");
      Serial.println(message);  // Imprime el mensaje recibido
    }
  }
}
```

Thanks

lewisxhe, 2024-05-23:
If you need to use a modem, then you'd better change Serial1 to Serial2, and you must set CDC On boot in the Arduino settings to 1, otherwise it will not work

manzajaro, 2024-05-23:
Thanks lewisxhe.

My idea is to run the project on battery power, as I read in the following comment for it to work without USB power, that field must be set to ‘disabled’. Will it work?

https://github.com/Xinyuan-LilyGO/LilyGo-T-SIM7080G/issues/38#issuecomment-1891335599

lewisxhe, 2024-05-24:
Yes, when you use the battery, just don't initialize Serial. Turn it on when you need to print and debug.

Closed 2024-05-29.

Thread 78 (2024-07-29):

PlatformIO Serial monitor doesn't give correct output

27rabbitlt, 2024-07-29:
Hi Lewis~

We are previously using SIM7000G and noticed SIM7080G seems better, so I tried SIM7080G with the same code.

It compiles, uploads correctly but when I tried to monitor Serial, the output is something like:

```
ESP-ROM:esp32s3-20210327
Build:Mar 27 2021
rst:0x8 (TG1WDT_SYS_RST),boot:0x28 (SPI_FAST_FLASH_BOOT)
Saved PC:0x40378832
SPIWP:0xee
mode:DIO, clock div:1
load:0x3fce3808,len:0x44c
load:0x403c9700,len:0xbe4
load:0x403cc700,len:0x2a38
entry 0x403c98d4
```

I found a post on forum but the I don't know how to apply that solution to platformIO's Serial monitor: https://community.platformio.org/t/esp32-s3-fh4n2-weact-studio-mini-wont-run-with-platformio-settings-several-issues/40442/3

The configuration file platformio.ini is copied from sample code:

```
[env:eride_tracker]
platform = espressif32@6.3.0
board = esp32s3box
framework = arduino
monitor_speed = 115200
lib_deps =
	knolleary/pubsubclient@^2.8
	vshymanskyy/TinyGSM@^0.11.5
	vshymanskyy/StreamDebugger@^1.0.1
	bblanchon/ArduinoJson@^6.18.3
	lewisxhe/XPowersLib@^0.2.1
	paulstoffregen/Time@^1.6.1
upload_speed = 921600
monitor_filters = default, log2file

build_flags =
    -DBOARD_HAS_PSRAM

    ; Enable UARDUINO_USB_CDC_ON_BOOT will start printing and wait for terminal access during startup
    -DARDUINO_USB_CDC_ON_BOOT=1

    ; Enable UARDUINO_USB_CDC_ON_BOOT will turn off printing and will not block when using the battery
    ; -UDARDUINO_USB_CDC_ON_BOOT

    -DTINY_GSM_MODEM_SIM7080
    -DTINY_GSM_RX_BUFFER=1024
    -DCAYENNE_PRINT=Serial
    -DCONFIG_BT_BLE_50_FEATURES_SUPPORTED

board_build.partitions = huge_app.csv

[platformio]
description = eride sim7000G prototyping
src_dir = src
```

Then I tried a example code and found that Serial output is correct. So it couldn't  be hardware problem.

Any hints or suggestions?

lewisxhe, 2024-08-22:
USB CDC needs to be set to 1

romwam, 2024-10-01:
I (successfully) use following defines in the platform.ini at "build_flags":
	-DARDUINO_USB_MODE=1
	-DARDUINO_USB_CDC_ON_BOOT=1

Closed 2024-10-04.

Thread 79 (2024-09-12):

External power supply with newer version of T-SIM7080?

romwam, 2024-09-12:
I have followed successfully the directions to power the device by external voltage as given in issue
https://github.com/Xinyuan-LilyGO/LilyGo-T-SIM7080G/issues/30 with my first samples of T-SIM7080 last year.

Unforunately on my newer board the diode is not on the board any more and connecting +5V to the indicated diode pad does not power up the board any more.

Please indicate how to power the T-SIM7080 using external 5V voltage for the newer boards where no diode is placed any more.

thank you,

Roman

lewisxhe, 2024-09-13:
The PCB is exactly the same, just removed the diodes and nothing else changed!

lewisxhe, 2024-09-13:
Yes

romwam, 2024-09-13:
Thank you very much for your quick response!

Closed 2024-10-04.

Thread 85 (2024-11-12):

Charging battery when power mechanical switch if OFF

smehner1, 2024-11-12:
Hi there,

Currently, the battery is only charged (via USB-C) when the mechanical switch is set to ON. This is not intuitive for the user and may lead to user errors.

I want to operate the LilyGo inside a case and route a charging port to the outside. Ideally, I would like to route the USB-C port to the outside so I can do debugging without having to open the case.

I’ve already found the JST connector for the solar input, but for the power supply (which could be any USB power adapter), I can’t ensure that it limits the charging current to a maximum of 500mA.

Does anyone have any ideas?

Best,

Stefan

lewisxhe, 2024-11-13:
https://github.com/Xinyuan-LilyGO/LilyGo-T-SIM7080G/issues/49

Closed 2024-12-28.

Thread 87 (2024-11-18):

Board Not Booting with USB Wall Charger

Unicorne3000b, 2024-11-18:
I'm experiencing an issue where my board works perfectly when connected to a PC via USB, but fails to boot when using a wall charger. I'm using the Arduino IDE for programming the board. I have disabled usb cdc on boot and set usb mode to USB-OTG.
The same USB cable is used for both the PC connection and the wall charger.
The wall charger supplies 2.4 A.
My Programm is using Serial1 for modem communication and serial2 to read external data.
Any insights or suggestions to resolve this issue would be greatly appreciated. Could this be related to insufficient current from the wall charger?

lewisxhe, 2024-11-20:
This problem exists in versions before 2.0.14. You need to turn it off and then you can start from the battery.
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

Closed 2025-01-04.

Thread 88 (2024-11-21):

Battery not supplying power

sporkyduck, 2024-11-21:
Hi!

One of several SIM70G:s I have has stopped supplying power when the mechanical battery switch is turned on. When switch is off, battery is not detected with pmu.isBatteryConnect(), which is normal. When switch is on, battery is detected with seems to be correct level percent  from pmu.getBatteryPercent(), ~100% at 4.16V. This is all while USB is connected. When I detach USB, power turns off.

Pressing PWR has once resultated in a very short startup try (GPS and modem LEDS came on) and but then off.

Is this a hardware or software issue, and how can I check?

Thanks!

lewisxhe, 2024-11-21:
You said you have several machines, and one of them has this problem?

lewisxhe, 2024-11-21:
Please turn on the switch, then connect the battery and test whether there is voltage here.
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

sponsoredlinks, 2024-11-25:
Note we have the same issue with our T-SIM7080G v1.0

Was working the other day but strangely - with a battery in it would not power up until USB-C was inserted - would then run fine

Now it doesn't work with either battery or battery  +USB

Voltage at the pin indicated in the picture is 4.050V

Is there anything else we can do to debug?

lewisxhe, 2024-11-25:
If there is voltage here, then the power supply has been connected to the PMU. Will pressing the PWR button not turn on the computer?

sponsoredlinks, 2024-11-25:
No, unfortunately not. We had just loaded the MinimalPowers reporting
sketch and then tried the MinimalPowersCurrent.

We then reverted to the MinimalPowersExample. Then it didnt turn on two
days later

We have tried pressing and holding each of the buttons

The issue with it being unable to power on with battery only (until you
plug usb, but then staying on even after usb detach) is possibly related?

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

lewisxhe, 2024-11-25:
Using [MinimalPowersCurrentExample](https://github.com/Xinyuan-LilyGO/LilyGo-T-SIM7080G/blob/master/examples/MinimalPowersCurrentExample/MinimalPowersCurrentExample.ino) , press the PWR button. Does it print anything?

sponsoredlinks, 2024-11-25:
I dont believe we can get it to power on to load the example? Will try
tomorrow and report back - thank you for the help

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

sponsoredlinks, 2024-11-26:
Thanks Lewis it turned out you were right

The examples have an endless loop at the start that waits for serial input to be connected

So if you just turn it on on battery, basically it waits endlessly for a serial connection and doesn't provide any signs of life until serial is plugged in ->
https://github.com/Xinyuan-LilyGO/LilyGo-T-SIM7080G/blob/master/examples/MinimalPowersExample/MinimalPowersExample.ino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

I may have missed it in the documentation but if not already there it might be worth making this obvious (or flashing the led perhaps  :)

thanks

lewisxhe, 2024-11-26:
OK, then it is actually started, and CDC is waiting for serial access

Closed 2025-01-09.

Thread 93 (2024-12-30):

In MinimalModemNBIOTExample, testAT never succeeds

eduard-firewave, 2024-12-30:
I'm running the MinimalModemNBIOTExample code and testAT method never succeeds. I see that "AT" is printed all the time in the SerialMonitor. I think it worked once on this device, but now it never works. Is there a way to reset the SIM module somehow?

Here is the sample output:
AT
�.AT
.AT
.AT
.AT
.AT
.AT
.AT
.Retry start modem .
AT
.AT
����.AT
.AT
.AT
.AT
��.AT
.AT
.Retry start modem .

lewisxhe, 2024-12-31:
1. Has the code been modified?
2. Is the red light next to the modem on?

lewisxhe, 2024-12-31:
Have you tried pressing and holding the ESP32 BOOT button and then plugging in the USB? Please note that there is a SIM BOOT button next to it, so don’t press the wrong one.

eduard-firewave, 2024-12-31:
1. The code hasn't been modified (besides the apn string), but previously another code was uploaded.
2. Yes, the red light is on and the other one beside it is blinking.

Thanks!

lewisxhe, 2024-12-31:
Have you changed the baud rate of the modem?

If the red light is flashing, the modem is normal. You can insert the micro-USB into the USB port next to the modem, install the SIM7080 driver, then select the AT port, change the baud rate to 115200, and then send AT to see if it returns OK

https://github.com/Xinyuan-LilyGO/LilyGo-T-SIM7080G/blob/master/docs/sim7080_update_firmware.md

lewisxhe, 2024-12-31:
The link is just to show you how to update the driver, please do not update the firmware

eduard-firewave, 2024-12-31:
Is there similar guide for mac?

lewisxhe, 2024-12-31:
Can only be used on Windows, no Mac

eduard-firewave, 2024-12-31:
will try on windows machine and will update... thanks for your support

eduard-firewave, 2024-12-31:
and now the update tool can not update again for some reason:

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

eduard-firewave, 2024-12-31:
It does seem to work from Arduino IDE though:
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

But still no success with the code from the example. It still doesn't get any response for AT command.

eduard-firewave, 2024-12-31:
I updated the baud rate using Arduino IDE Serial Monitor and the "AT+IPR=115200" command, and it fixed the issue. Thanks for you support!

I f I can, a follow up question:
Is it possible to increase the baud rate of the AT port?

Thanks!

Closed 2025-01-01.

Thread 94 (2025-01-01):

SD card example throws errors randomly

eduard-firewave, 2025-01-01:
Hi, I'm running the SD Card example and I get the errors on each run. The errors seem to appear in random places - not consistently. Here is the sample output:

SD_MMC Card Type: SDHC
SD_MMC Card Size: 29819MB
Listing directory: /
  FILE: datalog.txt  SIZE: 15690823
  FILE: tmp.raw  SIZE: 353280
  FILE: currentVersion  SIZE: 1
  DIR : .Spotlight-V100
  DIR : .fseventsd
  FILE: ._datalog.txt  SIZE: 4096
  FILE: ._tmp.raw  SIZE: 4096
  FILE: test.txt  SIZE: 0
  FILE: foo.txt  SIZE: 13
Creating Dir: /mydir
**E (4751) sdmmc_req: sdmmc_host_wait_for_event returned 0x107
E (4751) diskio_sdmmc: sdmmc_write_blocks failed (263)
E (4752) sdmmc_cmd: sdmmc_read_sectors_dma: sdmmc_send_cmd returned 0x109
E (4757) diskio_sdmmc: sdmmc_read_blocks failed (265)**
mkdir failed
Listing directory: /
**E (4763) sdmmc_req: handle_idle_state_events unhandled: 00000008 00000002**
  FILE: datalog.txt  SIZE: 15690823
  FILE: tmp.raw  SIZE: 353280
  FILE: currentVersion  SIZE: 1
  DIR : .Spotlight-V100
  DIR : .fseventsd
  FILE: ._datalog.txt  SIZE: 4096
  FILE: ._tmp.raw  SIZE: 4096
  FILE: test.txt  SIZE: 0
  FILE: foo.txt  SIZE: 13
Removing Dir: /mydir
**[  4878][E][vfs_api.cpp:250] rmdir(): /mydir does not exists or is a file**
rmdir failed
Listing directory: /
  FILE: datalog.txt  SIZE: 15690823
  FILE: tmp.raw  SIZE: 353280
  FILE: currentVersion  SIZE: 1
  DIR : .Spotlight-V100
Listing directory: /.Spotlight-V100
  DIR : Store-V2
Listing directory: /.Spotlight-V100/Store-V2
  DIR : 42E83897-C3B2-4FA8-954A-0313405B4665
  FILE: VolumeConfiguration.plist  SIZE: 4506
  DIR : .fseventsd
Listing directory: /.fseventsd
  FILE: fseventsd-uuid  SIZE: 36
  FILE: ._datalog.txt  SIZE: 4096
  FILE: ._tmp.raw  SIZE: 4096
  FILE: test.txt  SIZE: 0
  FILE: foo.txt  SIZE: 13
Writing file: /hello.txt
File written
Appending to file: /hello.txt
Message appended
Reading file: /hello.txt
Read from file: Hello World!
Deleting file: /foo.txt
File deleted
Renaming file /hello.txt to /foo.txt
File renamed
Reading file: /foo.txt
Read from file: Hello World!
0 bytes read for 0 ms
**E (4849) sdmmc_req: handle_idle_state_events unhandled: 00000042 00000000
E (4854) sdmmc_req: handle_idle_state_events unhandled: 00000042 00000000
E (4861) sdmmc_req: handle_idle_state_events unhandled: 00000040 00000000
E (4865) sdmmc_req: handle_idle_state_events unhandled: 00000042 00000000
E (4867) sdmmc_req: handle_idle_state_events unhandled: 00000042 00000000
E (5871) sdmmc_req: sdmmc_host_wait_for_event returned 0x107
E (5871) diskio_sdmmc: sdmmc_write_blocks failed (263)
E (6872) sdmmc_req: sdmmc_host_wait_for_event returned 0x107
E (6872) diskio_sdmmc: Check status failed (0x107)
E (7873) sdmmc_req: sdmmc_host_wait_for_event returned 0x107**

eduard-firewave, 2025-01-02:
It stopped recognizing the card now. Tried several SD cards (all work on the PC and are FAT32 formated). Actually tried several T-SIM7080 boards as well. And the same SD card is working on T-SIM7670G board.

lewisxhe, 2025-01-03:
A7670 uses SPI driver, while SIM7080 uses SDMMC 1bit mode. It seems that the problem has been fixed in versions greater than 3.0. You can test it.
https://github.com/espressif/arduino-esp32/issues/7373

eduard-firewave, 2025-01-05:
I am using the platformio with vscode. I upated the env to
[env:t-camera-sim7080]
platform = espressif32 @ 6.9.0
framework = arduino
board = esp32s3box

and it solved the issue.
Thanks so much for your support!

Closed 2025-01-05.

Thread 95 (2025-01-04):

GPS signal acquisition is taking a long time

FallingSnow, 2025-01-04:
I have my device connected via USB and the included GPS antenna attached. However I struggle to get a fix waiting 30 minutes and still not getting a fix. I'm using the `MinimalModemGPSExample`.

Where I have my device is particularly difficult to get GPS signal, since my Pixel 8 Pro also struggles just as much to get signal without downloading GPS assistance data. However if I get a fix outside, then move back indoors I maintain that fix.

My question is mostly about what I can do to help with signal acquisition. Should I get a better antenna? It there some combination of `AT+CGNSWARM` or `AT+CGNSHOT` I can use to help?

lewisxhe, 2025-01-06:
You can only replace a better active GPS antenna to improve the GPS signal sensitivity. AT+CGNSWARM is useless for this module. Unless you keep the GPS powered, turning off the GPS will completely cut off the power.

FallingSnow, 2025-01-09:
I have a battery connected. To keep the module powered do I have to avoid calling `AT+CPOWD=1` and `PMU.disableDC3()` when trying to deepsleep?

lewisxhe, 2025-01-09:
Yes.

FallingSnow, 2025-03-04:
Do you know if it's possible to just keep the memory powered so you don't need to do a cold start everytime instead of having to keep the whole modem powered at ~30mA?

I assume it should be possible since PSM claims to use 3.2uA.

Closed 2025-01-10.

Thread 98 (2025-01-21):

Unexpected NORMAL POWER DOWN

eduard-firewave, 2025-01-21:
I get 'NORMAL POWER DOWN' printed every second time I run the same code. The module is connected via Type-C and in setup I have the PMU code as in the example:
```
  if (!PMU.begin(Wire, AXP2101_SLAVE_ADDRESS, I2C_SDA, I2C_SCL))
  {
    Serial.println("Failed to initialize power.....");
    while (1)
    {
      delay(5000);
    }
  }

  // If it is a power cycle, turn off the modem power. Then restart it
  if (esp_sleep_get_wakeup_cause() == ESP_SLEEP_WAKEUP_UNDEFINED)
  {
    PMU.disableDC3();
    // Wait a minute
    delay(200);
  }

  // Set the working voltage of the modem, please do not modify the parameters
  PMU.setDC3Voltage(3000); // SIM7080 Modem main power channel 2700~ 3400V
  PMU.enableDC3();

  // Modem GPS Power channel
  PMU.setBLDO2Voltage(3300);
  PMU.enableBLDO2(); // The antenna power must be turned on to use the GPS function

  // Set the working voltage of the sdcard, please do not modify the parameters
  PMU.setALDO3Voltage(3300); // SD Card VDD 3300
  PMU.enableALDO3();

  // TS Pin detection must be disable, otherwise it cannot be charged
  PMU.disableTSPinMeasure();
```

Then it tries to connect to the network and goes to sleep for 10 seconds and then runs again.
Here is the output of 2 consecutive runs where 1st run is successful and the second run fails:
```
Reconnecting to /dev/cu.usbmodem2101 .....       Connected!

Mounting SD Card
SD_MMC Card Type: SDHC
SD_MMC Card Size: 29819MB
Initializing logging...
I: Logger initialized
I: Begin SerialAT at 115200
I: Testing AT commands...
AT
AT
AT
AT

RDY
I: .
AT
AT
OK
I: AT Test OK
I: Modem started!
I: Start modem...
I: Testing AT commands...
AT
AT
OK
I: AT Test OK
AT+CPIN?
AT+CPIN?
+CPIN: READY

OK
I: SIM card online
AT+CNMP=2

+CFUN: 1

+CPIN: READY

SMS Ready
AT
AT+CNMP=2
OK
ATE0
AT
OK
AT
ATE0
OK
ATE0

OK
AT

OK
AT+CMEE=0

OK
AT+CLTS=1

OK
AT+CBATCHK=1

OK
AT+CPIN?

OK

+CPIN: READY

OK
AT+CMNB=1

OK
I: Setting network APN. APN: net.hotm
AT+CGDCONT=1,"IP","net.hotm","0.0.0.0",0,0

OK
I: APN set successfully. APN: net.hotm
I: Setting network MCC: 425 MNC: 07
AT+COPS=1,2,"42507"

DST: 0

*PSUTTZ: 25/01/21,14:41:52","+08",0

+CTZV: 8

OK
I: Operator registered successfully: 42507
I: Wait for the modem to register with the network.
AT+CEREG?

+CEREG: 0,1

OK
I: Online registration successful
I: Registration Status: 1
I: Connecting to network...
AT+CNACT=0,0

ERROR
AT+CGDCONT=1,"IP","net.hotm"

OK
AT+CGATT=1

OK
AT+CGNAPN

+CGNAPN: 1,"net.hotm"

OK
AT+CNCFG=0,1,"net.hotm"

OK
AT+CNACT=0,1

OK

+APP PDP: 0,ACTIVE
AT+CGATT?

+CGATT: 1

OK
AT+CNACT?

+CNACT: 0,1,"10.57.208.200"
+CNACT: 1,0,"0.0.0.0"
+CNACT: 2,0,"0.0.0.0"
+CNACT: 3,0,"0.0.0.0"

OK
AT+CNACT=0,0

OK
AT+CGATT=0

+APP PDP: 0,DEACTIVE

OK
I: TCP connection closed and GPRS disconnected.
I: Going to sleep for 10 seconds
Disconnected (read failed: [Errno 6] Device not configured)
Reconnecting to /dev/cu.usbmodem2101 .....       Connected!

Mounting SD Card
SD_MMC Card Type: SDHC
SD_MMC Card Size: 29819MB
Initializing logging...
I: Logger initialized
I: Begin SerialAT at 115200
I: Testing AT commands...
AT

NORMAL POWER DOWN

OK
I: AT Test OK
I: Modem started!
I: Start modem...
I: Testing AT commands...
AT

OK
I: AT Test OK
AT+CPIN?

+CPIN: READY

OK
I: SIM card online
AT+CNMP=2
AT+CMNB=1
I: Setting network APN. APN: net.hotm
AT+CGDCONT=1,"IP","net.hotm","0.0.0.0",0,0
I: Failed to set APN
AT+CGATT?
I: GPRS is not connected.
I: Going to sleep for 10 seconds
Disconnected (read failed: [Errno 6] Device not configured)
```

**Note that in the 2nd run it prints 'NORMAL POWER DOWN' and then everything goes wrong. Can't understand the reason. **

lewisxhe, 2025-01-22:
Didn't you see the description here?
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

lewisxhe, 2025-01-22:
I uploaded a simple test case, which does not have the problem you mentioned.

Closed 2025-03-07.

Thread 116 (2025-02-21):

About GPS receiver model and PPS Signal

RenzoFurlani, 2025-02-21:
Hello,

How are you? Fine?

Yes, there are many other boards from your excelent LilyGo products, but , now, we are looking for some technical specific characteristics.

These are:

We need a PPS signal from GPS receiver.
It is important to use a uBlox receiver for its quality, but we are open to other receivers, with similar qualities.
We need to know more about the functionalities of the Battery Management System, for battery charging and battery loading, and for know how we can charge this lithium battery.
We need yes or yes a SD card slot.
Lora is not important for us, we would use BT for near communication.
We need to comunicate with external ADC devices, using SPI protocol.
Could you met me with some engineer from your company, please?

Best regards,

Renzo

lewisxhe, 2025-02-22:
7080G does not have PPS, and all LilyGo modems do not have PPS connected to ESP. So you need an external GPS module

7080G board carries PMU battery management chip, automatic charge and discharge management, but there is a disadvantage that if it is turned off, it cannot be turned on automatically and must be turned on manually.

SPI, I2C are the most basic, and all include these functions

RenzoFurlani, 2025-02-24:
Hello , Many thanks for your quick answer.

Please, could you advice me what is the best LilyGo to do a GPS based precise time syncronization and with SD card inside it?

Best regards,

Renzo

lewisxhe, 2025-02-25:
There is no PPS function in the LTE series.
For PPS function and SD, you can consider T-BeamS3

RenzoFurlani, 2025-02-25:
Many thanks,
Some other questions about T Beam series?
The "S3" mean that ESP32 is S3 model?
I see some T-Beams boards and I like theses. But in anything of that boards -i have seen a SD card socket.
T-BEAMS3 is not in the main web page of LilyGo, it is very new?

lewisxhe, 2025-02-26:
1. Yes , ESP32S3
2. Yes ,it have sd socket
3. It can be found here https://lilygo.cc/products/t-beam-supreme?_pos=5&_sid=1682ba2a0&_ss=r

RenzoFurlani, 2025-02-26:
Many thanks for your answers.

All the T BEAM have SD cards and Ublox with PPS connected to ESP32?

IF you have more details , more than the information of T-BEAMs put in the web page, I would appriciate you a lot.

lewisxhe, 2025-02-27:
Only T-BeamS3 has SD and PPS, the ESP32 version does not.

RenzoFurlani, 2025-03-13:
Dear LilyGo sales support.
We are planning tu buy 20 units of some of your dev boards, and I have some changes in our requirements.
We , up now, do not need for GPS receiver and PPS signal. It could be done by a external module, may be ublox, connected to ESP32 by UART.
But we need a LilyGO board with Battery Managament chip, with SD or TF CARD, and to be programmable with Visual Code and IDF Libraries (I think this last issue es no a problem for any of your boards, but I am asking you).
We do not need both, any kind of LoRa or similar comunication and LCD display. There are more basic boards without these functionalities?
Just only need a SPI and UART port for external comunication.
Best regards,
Renzo

lewisxhe, 2025-03-17:
This may be what you are looking for https://lilygo.cc/products/t7-s3

RenzoFurlani, 2025-03-17:
Lweisxhe, many thanks.
Your recomendation is very nice dev board, with a nice price too, but it dont have:
SD or TD Card support.
Power Management System, with input for 18650 lithium battery and solar panel.

This two charcteristics are only we need for a LilyGo board. I would repeat that we dont need LoRa, GPS, GSM or SIM support, and any kind of display.
There are some other boards that fit these two items?
Best regards,
Renzo

lewisxhe, 2025-03-18:
This board has battery management and 18650, but no SD card holder. You said that only T-Beam is suitable for you at present, but it has LoRa and GPS.
https://lilygo.cc/products/t-energy-s3
https://lilygo.cc/products/t-beam-softrf

RenzoFurlani, 2025-03-18:
Dear Lweisxhe,
Many thanks... so in conclusion, there are not a board from LiLygo that adapt to all my requeriments, and some other electronics components like SD CARD, GPS receiver,  or Power Managment devices must be integrated from other electronics manufactures, at least that LiLyGO can sell us as a sepated component.
We have to work in whitch of these devices should be integrated as external devices, and which other would be assemted in th LiLyGo board.
One of the last questions is about what is the IDE for progrramming this devices? We must program them ESP32 in Visual Code, using IDF Framework. This IDE and toolset is applied for all the LiLyGo ESP32 boards?
Best regards,
Renzo

lewisxhe, 2025-03-19:
ESP32 basically supports it, there is no question of whether the board supports it or not.

RenzoFurlani, 2025-03-20:
Many thanks,

I will do a complete revision of ech of your products, in order to select the best option for us.
Our priorities are SD or TF card and PMU or some power managament , both, on board wih ESP32. Then, explore avaliable pin out for connecting GPS with PPS and also ADC over SPI .
Lora and TFT or similar display will not use for us, but if this are on board, we cannot do anything.

RenzoFurlani, 2025-03-26:
Dear Lweisxhe,
We are planning to afford and buy twenty LiLyGO T8 ESP S3 units, with a T-BAT for battery module. We can connect both devices? are they compatible with the same voltage and connectors?
In other hand, the model T8 support both , WiFi and Bluetooth (LE). We are planning to do some monitoring evaluation using BLE or BT for near communications.
Last question is about SPI. In the T8, one SPI port are connected physically and logically to SD card. That is almost obvious. But what about the other SPI? Can we map it to some of physical pin and then connect ADC boards to it ?
The T8 model are two version, and it depends if ESP 32 are S3 or C3. If it is S3, the NC pins disappear and they are now ready to use ? That is important for us, beacause we are planning to use several pins from ESP32 to connect external devices such as ADC boards, GPS, leds, and other things.
Many thanks.

lewisxhe, 2025-03-27:
ESP32S3 SPI can be freely mapped, and there are three available SPI masters that can be freely assigned.

T-BAT is just a power supply module, but it has an additional solar charging function. T8 also has its own charging function. If you want to use it together, it is also possible.

However, I suggest you first evaluate whether you need to use it this way

RenzoFurlani, 2025-03-28:
Hello,
We are going to buy some of your boards.
Your products will be shipped to Argentina, and there are only one option in your webpage, by Fedex.
Do you have other option than this? Fedex is not working well in Argentina, doing expensive custom local cost, and shipping cost is huge in comparasion to others companies.
DHL is working wonderful for here . Could you work with this company?
Many Thanks,

lewisxhe, 2025-04-23:
You need to contact the salesperson at the lilygo store, I am not responsible for these.

Closed 2025-06-06.

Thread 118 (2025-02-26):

T-SIM7080G battery insertion issue (old batch vs. new batch)

Peer77, 2025-02-26:
Hi Lewis,
hope you are doing OK.

Would be great if you could advise on the following, it is quite a big issue.

The situation: I have received a new batch of ESP32S3 with SIM7080G, which is now coming without the big diode next to the USB-C connector. So it makes it a bit easier to skip the removal and proceed right away with soldering the cable to the upper pad to feed 5V into it (as described in issue  #49) Very nice!

While testing the new batch against the old version (came with diode , and diode has been removed afterwards) I used the exact same repository for both batch versions, but got different results:

OLD BATCH:
    ⁃    inserting 18650 and have physical switch switched in direction of USB-C connector, the LilyGo remained switched off and only came to live when 5V was fed to the pad where the diode was located (as desired)
    ⁃    When 5V is removed, I used PMU.isVbusIn() to trigger a timer to switch off the Lilygo after 30s via calling PMU.shutdown(). This works very well.

NEW BATCH:
    ⁃    after having inserted the 18650, the Lilygo switches on right away (when switch is ON) despite the absence of 5V!
    ⁃    Also, after calling PMU.shutdown(), I can see that the powerlines for the modem are shutdown (as expected), but the VSYS voltage is not being shutdown(the connected LED remains lit)

I updated also the XPowerLib to latest version to check if this fixes the problem, but the issue remains.

Is there a fix for this issue to bring back the old behaviour (seen on old batch)? It is a significant change.

Thanks in advance, any advice is much appreciated.

Greetings, regards,
Peer

lewisxhe, 2025-02-27:
Hi, Peer

1. The new version AXP2101 has changed the default configuration at the factory, and the default setting is to automatically start the machine when the battery is inserted.
2. In the new version, VSYS will not turn off the output when the machine is turned off, but will keep output
In general, the new SIM7080G uses the newly configured AXP2101.

Closed 2025-04-12.

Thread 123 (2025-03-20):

SD Card not working

carmi55, 2025-03-20:
Platform IO program: examples/MinimalSDCardExample

Seriel Monitor output:
>>E (16452) sdmmc_req: sdmmc_host_wait_for_event returned 0x107
E (16452) sdmmc_sd: sdmmc_check_scr: send_scr returned 0x107
E (16453) vfs_fat_sdmmc: sdmmc_card_init failed (0x107).
[ 16557][E][SD_MMC.cpp:138] begin(): Failed to initialize the card (0x107). Make sure SD card lines have pull-up resistors in place.
Card Mount Failed >>

Missing pull up resistors on TF-Card holder DAT3 (+DAT1 + DAT2) lines !
According to schematics the LILIGO T-SIM7080 TF card holder has only pull up resistors on SD_DAT0 (40),SD_CLK(38) and SD_CMD(39).

"SD pull-up requirements apply to cases where ESP32 uses the SPI or SDMMC controller to communicate with SD cards. When an SD card is operating in SPI mode or 1-bit SD mode, the CMD and DATA (DAT0 - DAT3) lines of the SD bus must be pulled up by 10 kOhm resistors. SD cards and SDIO devices should also have pull-ups on all above-mentioned lines (regardless of whether these lines are connected to the host) in order to prevent them from entering a wrong state."

https://docs.espressif.com/projects/esp-idf/en/stable/esp32/api-reference/peripherals/sd_pullup_requirements.html

carmi55, 2025-03-20:
https://github.com/Xinyuan-LilyGO/T-Embed-CC1101/blob/master/hardware/T-Embed-CC1101%20V1.0%2024-07-29.pdf   has D3 connected to CS !

lewisxhe, 2025-03-22:
What SD card do you use? We tested using SanDisk SD and found no problems. You are talking about using SD 4-bit mode, each GPIO needs to be pulled up, while 1-bit mode only needs to set the 3 GPIOs used to be pulled up.

grf14, 2025-04-04:
Almost same problem for me. I'm testing the example code and this is the output:
E (3098) sdmmc_sd: sdmmc_check_scr: send_scr returned 0x109
E (3099) vfs_fat_sdmmc: sdmmc_card_init failed (0x109).
[  3210][E][SD_MMC.cpp:138] begin(): Failed to initialize the card (0x109). Make sure SD card lines have pull-up resistors in place.
Card Mount Failed

grf14, 2025-04-07:
I made it work. I modify the frequency here:

SD_MMC.begin("/sdcard", true, false ,SDMMC_FREQ_PROBING)

lewisxhe, 2025-04-08:
So what frequency did you change to?

We tested using a SanDisk SD card, and the default frequency was able to pass the test.

grf14, 2025-04-08:
From 20MHz (default) to 400kHz. I follow this recommendation: https://github.com/espressif/esp-idf/issues/2478#issuecomment-424918316

These are the predefined variables of the library, they are in "sdmmc_types.h":

#define SDMMC_FREQ_DEFAULT      20000       /*!< SD/MMC Default speed (limited by clock divider) */
#define SDMMC_FREQ_HIGHSPEED    40000       /*!< SD High speed (limited by clock divider) */
#define SDMMC_FREQ_PROBING      400         /*!< SD/MMC probing speed */

carmi55, 2025-04-08:
I used:
- San Disk Ultra 16GB   -> didn't work
- San Disk Extreme 16GB -> didn't work
- Old San Disk 1GB  (12 years old) ... worked  ??

lewisxhe, 2025-04-09:
It seems to be a compatibility issue. We are also using San Disk Ultra 16GB.

grf14, 2025-04-09:
I'm using a San Disk Ultra 16GB too.

carmi55, 2025-04-30:
Got the SD Cards finally working:

- Step1:  set format_if_mount_failed = true  -> card is recognized, but no files/directories can be read or written
- Step2: set #define BOARD_MAX_SDMMC_FREQ  SDMMC_FREQ_DEFAULT -> everything in the SD_Card Test is working.

Closed 2025-06-14.

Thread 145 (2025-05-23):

T-SIM7080-S3 board possibly bricked by PMU configuration

gentileromi, 2025-05-23:
Hi LilyGO team,

I'm having a serious issue with my T-SIM7080-S3 board (ESP32-S3). After flashing the original firmware using the official ESP Web Flasher (https://espressif.github.io/esptool-js/), the board stopped responding. Here's a full description of the issue:

1. The firmware upload completes successfully with hash verification.
2. After flashing, no LEDs turn on and the board shows no activity over Serial at 115200 baud.
3. When I disconnect and reconnect the board, it enters a reboot loop: it keeps connecting and disconnecting from USB.
4. I tried the following recovery steps:
   - `pio run -t erase` using PlatformIO
   - `esptool.py erase_flash`
   - Flashing a minimal "Hello world" bin via Chrome
   - Forcing BOOT mode (holding BOOT + tapping RST) and uploading again
   - Switching USB ports and cables
   - Opening Serial Monitor at 115200 baud (shows 0xFFFFFFFF garbage or nothing)

Despite all this, the board only becomes temporarily stable in BOOT mode. As soon as I disconnect it or hit reset, it goes back into the loop.

I'm afraid the PMU (AXP2101) persisted a configuration that disables the ESP32 power rail (DC1 or DC3). This makes the board unrecoverable from software, even after erasing the flash.

Can you please confirm if there's a way to reset the PMU to default? Or reflash it via I2C?
If this is not fixable, is there any warranty or replacement process?

Thank you in advance,
Romina Gentile

gentileromi, 2025-05-23:
My board, for the moment, doesn't have sim and battery, it is just connected by USB

gentileromi, 2025-06-13:
thanks!!!! download mode worked!!

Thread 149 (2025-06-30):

Battery-only power-up requires manual PWR button press to boot

gusgonnet, 2025-06-30:
Hi,

I have two devices running the same user firmware.
Both devices are connected to a battery, battery is full in both cases.

Device 1:
- the device is disconnected via USB from my computer.
- I switch it on with the ON/OFF switch, the device boots and proceeds with executing my firmware.
- This is the expected behavior.

Device 2:
- the device is disconnected via USB from my computer.
- I switch it on with the ON/OFF switch, the device DOES NOT boot.
- by fooling around, I discovered that I need to tap on the PWR button for a couple of seconds.
- This is NOT the expected behavior.

Observations:
- Both devices boot fine when I connect them via USB to my computer.
- If I swap the batteries, nothing changes (this rules out a problem in the battery)

What is happening on device 2 and how can I fix it so the device boots up when I switch it on via the onboard ON/OFF switch when connected to a battery?

I have played with these settings on the platformio.ini file, still no improvements:

    ; Enable UARDUINO_USB_CDC_ON_BOOT will start printing and wait for terminal access during startup
    ; -DARDUINO_USB_CDC_ON_BOOT=1

    ; Enable UARDUINO_USB_CDC_ON_BOOT will turn off printing and will not block when using the battery
    -UARDUINO_USB_CDC_ON_BOOT

Thank you

How I'm using it:

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

lewisxhe, 2025-07-01:
These are two versions of PMU. When did you purchase them? Did you purchase them from our store?
https://github.com/Xinyuan-LilyGO/LilyGo-T-SIM7080G/issues/118

gusgonnet, 2025-07-01:
I purchased them around two months ago, one from the Lilygo AliExpress store and another one from a distributor in Canada.
So, should I conclude there is no way to fix the behavior on the device?
Thanks

gusgonnet, 2025-07-01:
ok, thanks.
Is there a way to tell them apart?

Example: Is the old one the one with the diode mentioned on issue  https://github.com/Xinyuan-LilyGO/LilyGo-T-SIM7080G/issues/49

And the new one does not have this diode?

Thank you

lewisxhe, 2025-07-01:
It can only be distinguished by behavior.

Closed 2025-07-01.

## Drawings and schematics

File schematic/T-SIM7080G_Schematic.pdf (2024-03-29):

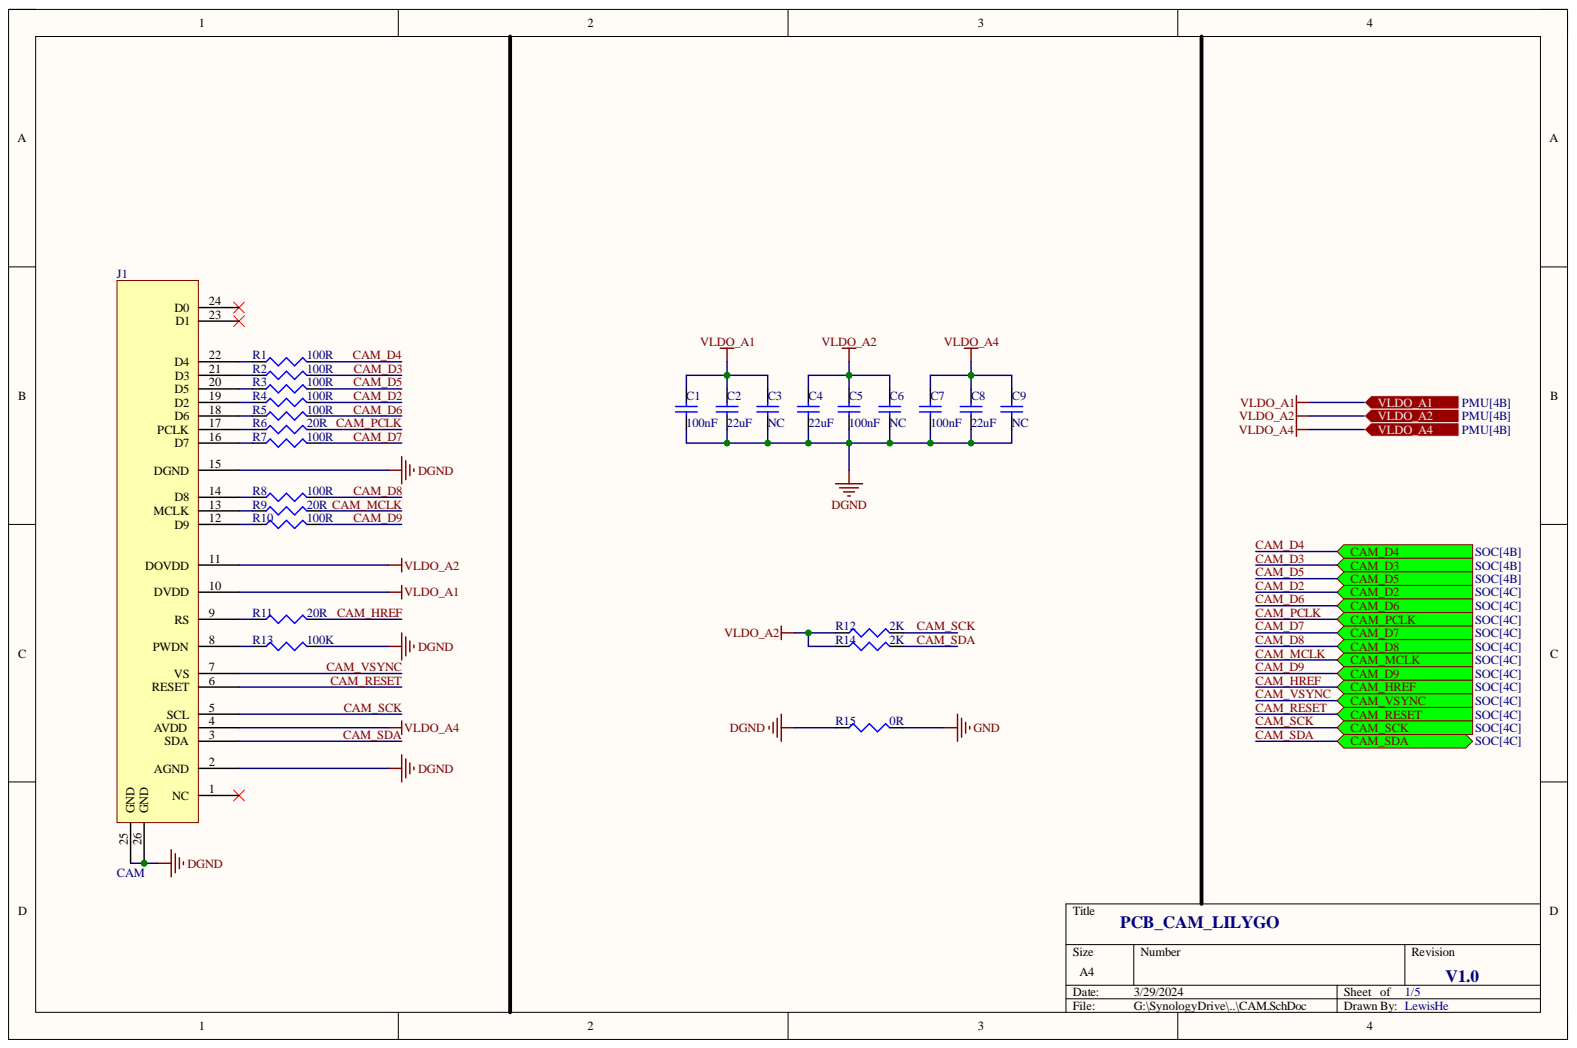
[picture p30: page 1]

Siz e A4 | Numb e r | R evisio n V1.

Da te : 3/29/202 4 | She et of
File : G:\SynologyDrive\. .\C AM . S c hD o c | Dr awn B y : Lewi s H e

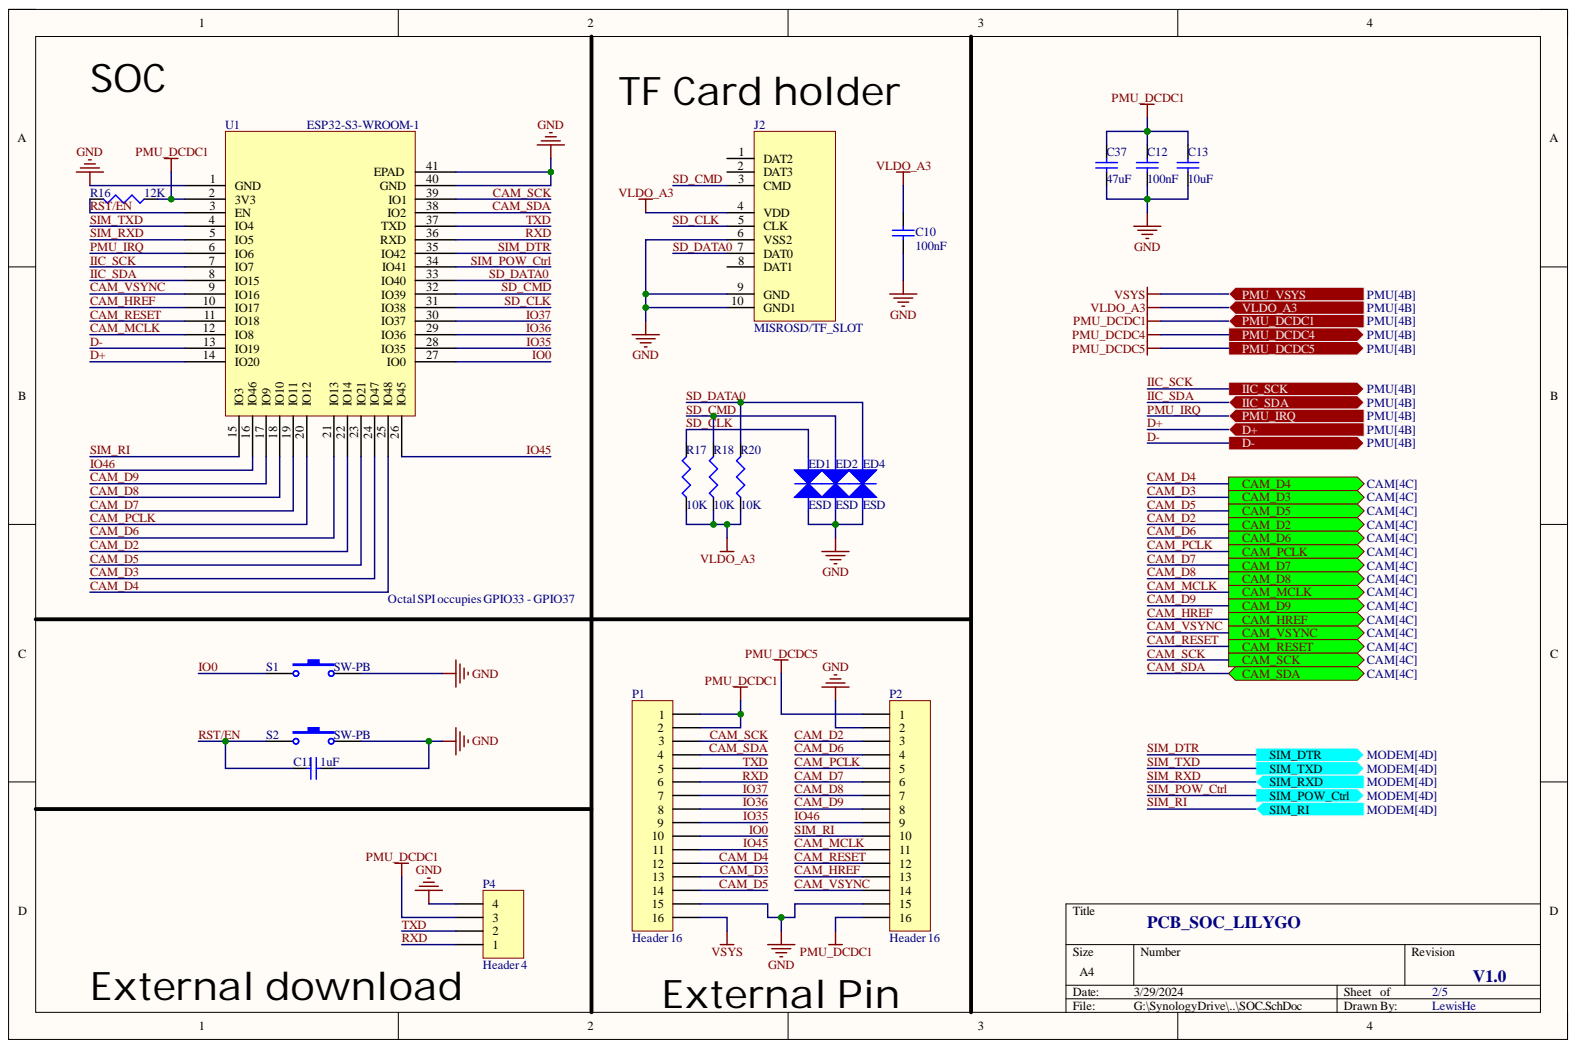
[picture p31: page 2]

2 | | CAM_S C K
3 | | CAM_S D A

Da te : 3/29/202 4 | She et of
File : G:\SynologyDrive\. .\S O C . S c hD o c | Dr awn B y : Lewi s H e

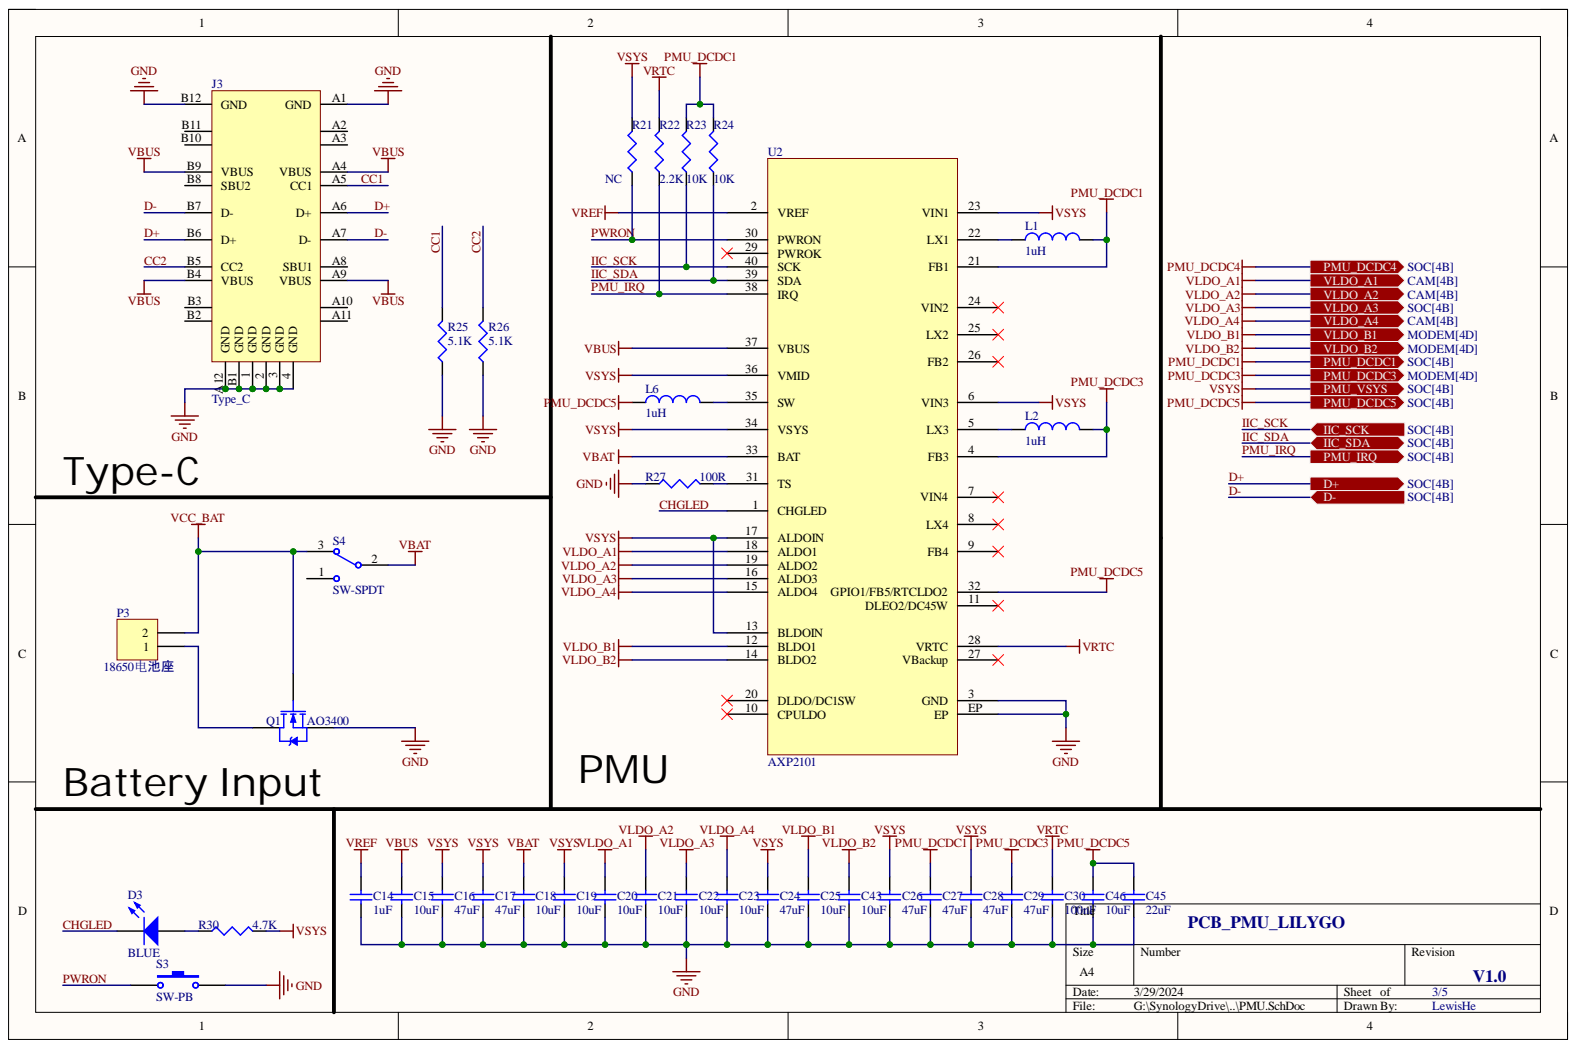
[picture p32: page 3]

ALDO1 18

ALDO4 15 ALDO3 16

BLDO1 12 BLDOIN 13

Date: 3/29/2024 | Sheet of
File: G:\SynologyDrive\..\PMU.SchDoc | Drawn By: LewisHe

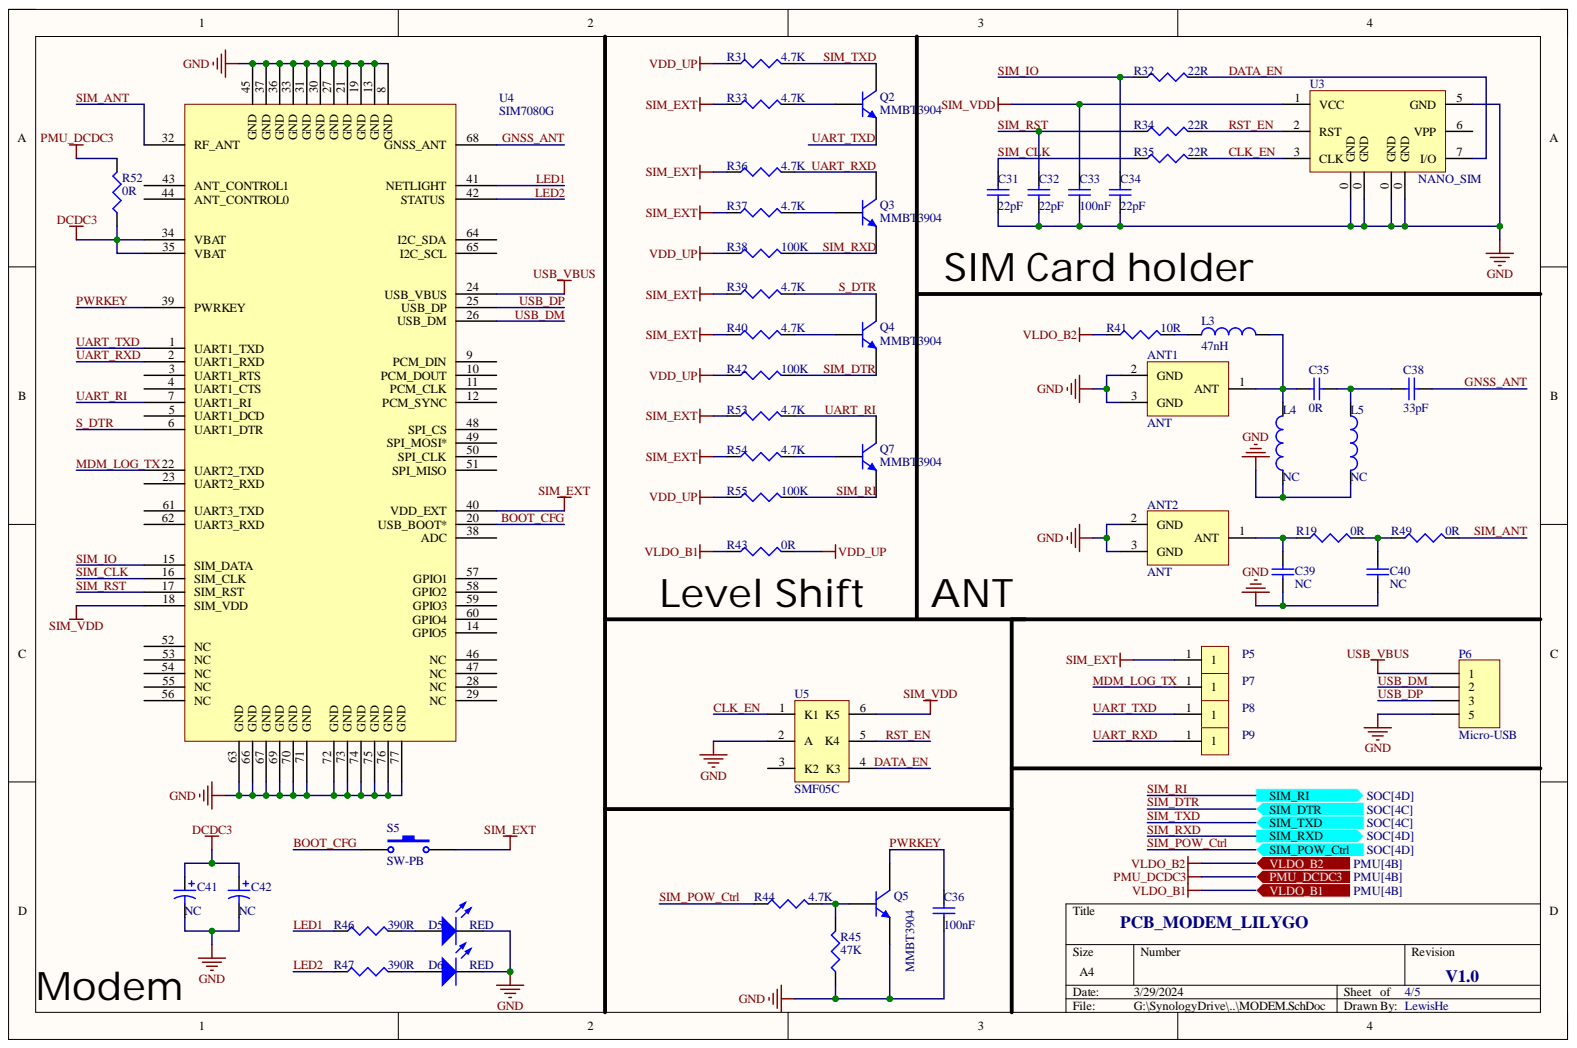
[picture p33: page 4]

Siz e A4 | Numb e r | R evisio n V1.

Da te : 3/29/202 4 | She et of
File : G:\SynologyDrive\. .\MO D EM . S c hD o c | Dr awn B y :

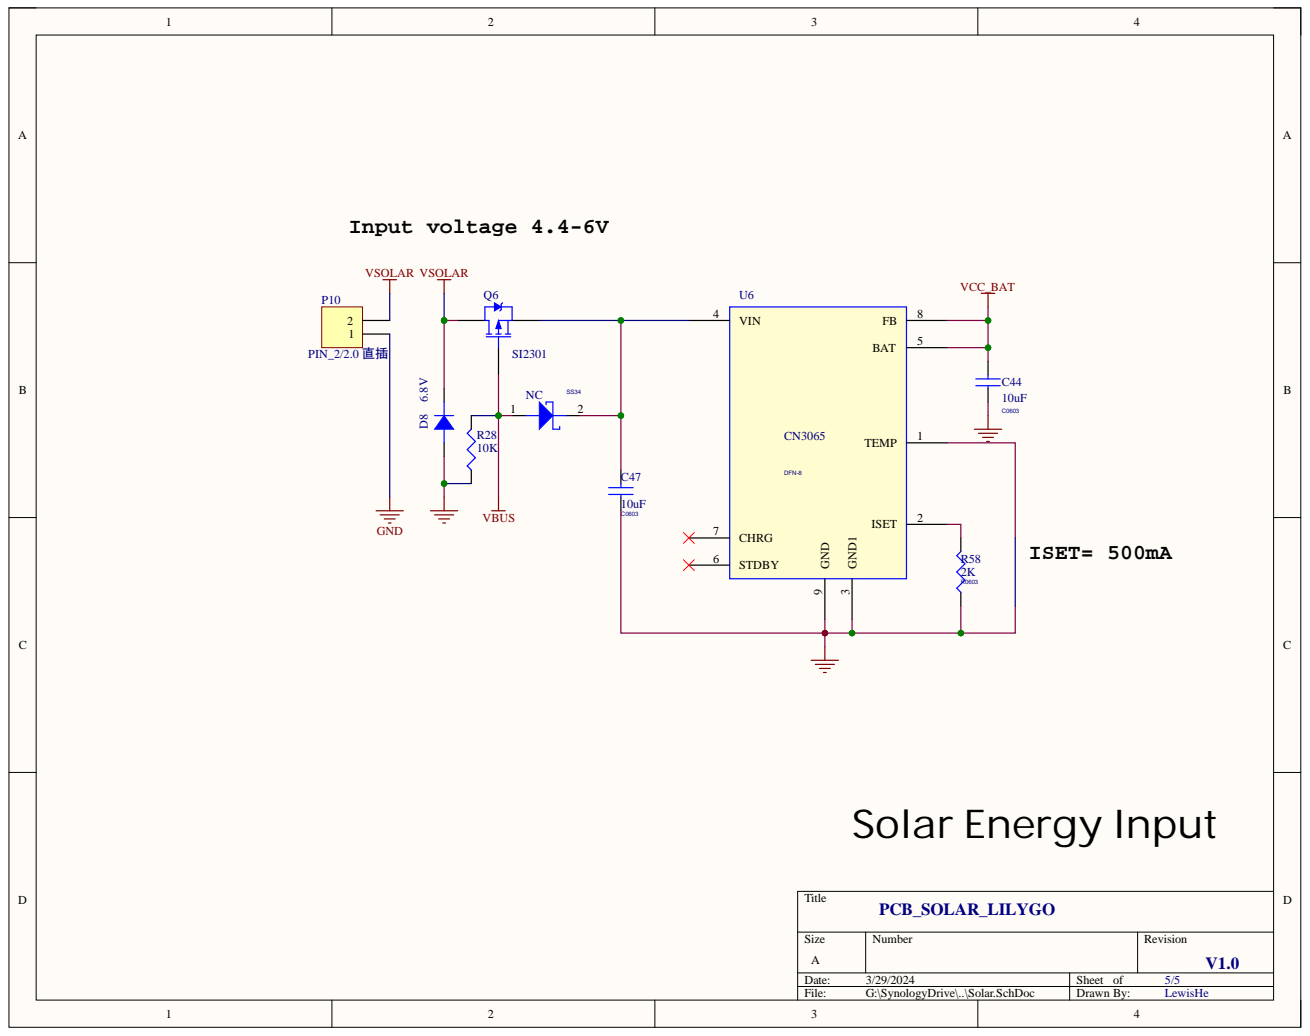
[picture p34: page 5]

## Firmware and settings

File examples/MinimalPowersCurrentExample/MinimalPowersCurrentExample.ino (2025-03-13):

/**
 * @file      MinimalPowersCurrentExample.ino
 * @author    Lewis He (lewishe@outlook.com)
 * @license   MIT
 * @copyright Copyright (c) 2024  Shenzhen Xin Yuan Electronic Technology Co., Ltd
 * @date      2024-03-29
 * @note      For the inability to set the charging current, please check this post https://github.com/Xinyuan-LilyGO/LilyGo-T-SIM7080G/issues/49
 * For setting a current greater than 500mA, the VBUS power supply must be sufficient. If the input is lower than 5V, the charging current will be below 500mA.
 */
#include <Arduino.h>
#define XPOWERS_CHIP_AXP2101
#include "XPowersLib.h"
#include "utilities.h"

XPowersPMU  PMU;

bool  pmu_flag = false;
uint32_t loopMillis;

void setFlag(void)
{
    pmu_flag = true;
}

void printChargerConstantCurr()
{
    const uint16_t currTable[] = {
        0, 0, 0, 0, 100, 125, 150, 175, 200, 300, 400, 500, 600, 700, 800, 900, 1000
    };
    uint8_t val = PMU.getChargerConstantCurr();
    Serial.printf("Setting Charge Target Current - VAL:%u CURRENT:%u\n", val, currTable[val]);
}

void setup()
{

    Serial.begin(115200);

    // Start while waiting for Serial monitoring
    while (!Serial);

    delay(3000);

    Serial.println();

    /*********************************
     *  step 1 : Initialize power chip,
     *  turn on modem and gps antenna power channel
    ***********************************/
    bool res;
    // Use Wire1
    res = PMU.begin(Wire1, AXP2101_SLAVE_ADDRESS, I2C_SDA, I2C_SCL);
    if (!res) {
        Serial.println("Failed to initialize power.....");
        while (1) {
            delay(5000);
        }
    }

    // If it is a power cycle, turn off the modem power. Then restart it
    if (esp_sleep_get_wakeup_cause() == ESP_SLEEP_WAKEUP_UNDEFINED ) {
        PMU.disableDC3();
        // Wait a minute
        delay(200);
    }

    // I2C sensor call example
    int sda = 13;  // You can also use other IO ports
    int scl = 21;  // You can also use other IO ports
    Wire.begin(sda, scl);

    //**\

    // Other i2c sensors can be externally connected to 13,21

    //**\


    Serial.printf("getID:0x%x\n", PMU.getChipID());

    // Set the minimum common working voltage of the PMU VBUS input,
    // below this value will turn off the PMU
    PMU.setVbusVoltageLimit(XPOWERS_AXP2101_VBUS_VOL_LIM_4V36);

    // Set the maximum current of the PMU VBUS input,
    // higher than this value will turn off the PMU
    PMU.setVbusCurrentLimit(XPOWERS_AXP2101_VBUS_CUR_LIM_1500MA);

    // Set VSY off voltage as 2600mV , Adjustment range 2600mV ~ 3300mV
    PMU.setSysPowerDownVoltage(2600);

    // TS Pin detection must be disable, otherwise it cannot be charged
    PMU.disableTSPinMeasure();

    /*********************************
     * step 2 : Enable internal ADC detection
    ***********************************/
    PMU.enableBattDetection();
    PMU.enableVbusVoltageMeasure();
    PMU.enableBattVoltageMeasure();
    PMU.enableSystemVoltageMeasure();


    /*********************************
     * step 3 : Set PMU interrupt
    ***********************************/
    pinMode(PMU_INPUT_PIN, INPUT);
    attachInterrupt(PMU_INPUT_PIN, setFlag, FALLING);

    // Disable all interrupts
    PMU.disableIRQ(XPOWERS_AXP2101_ALL_IRQ);
    // Clear all interrupt flags
    PMU.clearIrqStatus();
    // Enable the required interrupt function
    PMU.enableIRQ(
        XPOWERS_AXP2101_BAT_INSERT_IRQ    | XPOWERS_AXP2101_BAT_REMOVE_IRQ      |   // BATTERY
        XPOWERS_AXP2101_VBUS_INSERT_IRQ   | XPOWERS_AXP2101_VBUS_REMOVE_IRQ     |   // VBUS
        XPOWERS_AXP2101_PKEY_SHORT_IRQ    | XPOWERS_AXP2101_PKEY_LONG_IRQ       |   // POWER KEY
        XPOWERS_AXP2101_BAT_CHG_DONE_IRQ  | XPOWERS_AXP2101_BAT_CHG_START_IRQ       // CHARGE
    );

    /*********************************
     * step 4 : Set PMU Charger params
    ***********************************/
    // Set the precharge charging current
    PMU.setPrechargeCurr(XPOWERS_AXP2101_PRECHARGE_50MA);
    // Set constant current charge current limit , 0mA disable charge
    PMU.setChargerConstantCurr(XPOWERS_AXP2101_CHG_CUR_0MA);
    // Set charge cut-off voltage
    PMU.setChargeTargetVoltage(XPOWERS_AXP2101_CHG_VOL_4V2);


    /*********************************
     * step 5 : Disable all power channel , Used to monitor charging current and exclude other load current consumption
    ***********************************/
    PMU.disableDC2();
    PMU.disableDC3();
    PMU.disableDC4();
    PMU.disableDC5();

    PMU.disableALDO1();
    PMU.disableALDO2();
    PMU.disableALDO3();
    PMU.disableALDO4();
    PMU.disableBLDO1();
    PMU.disableBLDO2();

    PMU.disableCPUSLDO();
    PMU.disableDLDO1();
    PMU.disableDLDO2();

    Serial.println("DCDC=======================================================================");
    Serial.printf("DC1  : %s   Voltage:%u mV \n",  PMU.isEnableDC1()  ? "+" : "-", PMU.getDC1Voltage());
    Serial.printf("DC2  : %s   Voltage:%u mV \n",  PMU.isEnableDC2()  ? "+" : "-", PMU.getDC2Voltage());
    Serial.printf("DC3  : %s   Voltage:%u mV \n",  PMU.isEnableDC3()  ? "+" : "-", PMU.getDC3Voltage());
    Serial.printf("DC4  : %s   Voltage:%u mV \n",  PMU.isEnableDC4()  ? "+" : "-", PMU.getDC4Voltage());
    Serial.printf("DC5  : %s   Voltage:%u mV \n",  PMU.isEnableDC5()  ? "+" : "-", PMU.getDC5Voltage());
    Serial.println("ALDO=======================================================================");
    Serial.printf("ALDO1: %s   Voltage:%u mV\n",  PMU.isEnableALDO1()  ? "+" : "-", PMU.getALDO1Voltage());
    Serial.printf("ALDO2: %s   Voltage:%u mV\n",  PMU.isEnableALDO2()  ? "+" : "-", PMU.getALDO2Voltage());
    Serial.printf("ALDO3: %s   Voltage:%u mV\n",  PMU.isEnableALDO3()  ? "+" : "-", PMU.getALDO3Voltage());
    Serial.printf("ALDO4: %s   Voltage:%u mV\n",  PMU.isEnableALDO4()  ? "+" : "-", PMU.getALDO4Voltage());
    Serial.println("BLDO=======================================================================");
    Serial.printf("BLDO1: %s   Voltage:%u mV\n",  PMU.isEnableBLDO1()  ? "+" : "-", PMU.getBLDO1Voltage());
    Serial.printf("BLDO2: %s   Voltage:%u mV\n",  PMU.isEnableBLDO2()  ? "+" : "-", PMU.getBLDO2Voltage());
    Serial.println("CPUSLDO====================================================================");
    Serial.printf("CPUSLDO: %s Voltage:%u mV\n",  PMU.isEnableCPUSLDO() ? "+" : "-", PMU.getCPUSLDOVoltage());
    Serial.println("DLDO=======================================================================");
    Serial.printf("DLDO1: %s   Voltage:%u mV\n",  PMU.isEnableDLDO1()  ? "+" : "-", PMU.getDLDO1Voltage());
    Serial.printf("DLDO2: %s   Voltage:%u mV\n",  PMU.isEnableDLDO2()  ? "+" : "-", PMU.getDLDO2Voltage());
    Serial.println("===========================================================================");

    /*
    The default setting is CHGLED is automatically controlled by the PMU.
    - XPOWERS_CHG_LED_OFF,
    - XPOWERS_CHG_LED_BLINK_1HZ,
    - XPOWERS_CHG_LED_BLINK_4HZ,
    - XPOWERS_CHG_LED_ON,
    - XPOWERS_CHG_LED_CTRL_CHG,
    * */
    PMU.setChargingLedMode(XPOWERS_CHG_LED_ON);

    // Print default setting current
    printChargerConstantCurr();
}

uint8_t curIndex = 4;

void loop()
{
    if (pmu_flag) {
        pmu_flag = false;
        // Get PMU Interrupt Status Register
        uint32_t status = PMU.getIrqStatus();
        if (PMU.isPekeyShortPressIrq()) {

            // Set constant current charge current limit
            // For setting a current greater than 500mA, the VBUS power supply must be sufficient. If the input is lower than 5V, the charging current will be below 500mA.
            if (!PMU.setChargerConstantCurr(curIndex)) {
                Serial.println("Setting Charger Constant Current Failed!");
            }
            printChargerConstantCurr();
            Serial.println("===========================");
            curIndex++;
            curIndex %= (XPOWERS_AXP2101_CHG_CUR_1000MA + 1);

            // Toggle CHG led
            PMU.setChargingLedMode(PMU.getChargingLedMode() != XPOWERS_CHG_LED_OFF ? XPOWERS_CHG_LED_OFF : XPOWERS_CHG_LED_ON);
        }
        // Clear PMU Interrupt Status Register
        PMU.clearIrqStatus();
    }

    delay(200);
}

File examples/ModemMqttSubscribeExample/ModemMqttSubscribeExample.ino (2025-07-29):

/**
 * @file      ModemMqttSubscribeExample.ino
 * @author    Lewis He (lewishe@outlook.com)
 * @license   MIT
 * @copyright Copyright (c) 2022  Shenzhen Xin Yuan Electronic Technology Co., Ltd
 * @date      2022-09-28
 *
 */
#include <Arduino.h>
#define XPOWERS_CHIP_AXP2101
#include "XPowersLib.h"
#include "utilities.h"

XPowersPMU  PMU;

// See all AT commands, if wanted
#define DUMP_AT_COMMANDS

#define TINY_GSM_RX_BUFFER 1024

#define TINY_GSM_MODEM_SIM7080
#include <TinyGsmClient.h>


#ifdef DUMP_AT_COMMANDS
#include <StreamDebugger.h>
StreamDebugger debugger(Serial1, Serial);
TinyGsm        modem(debugger);
#else
TinyGsm        modem(SerialAT);
#endif

const char *register_info[] = {
    "Not registered, MT is not currently searching an operator to register to. The GPRS service is disabled, the UE is allowed to attach for GPRS if requested by the user.",
    "Registered, home network.",
    "Not registered, but MT is currently trying to attach or searching an operator to register to. The GPRS service is enabled, but an allowable PLMN is currently not available. The UE will start a GPRS attach as soon as an allowable PLMN is available.",
    "Registration denied, the GPRS service is disabled, the UE is not allowed to attach for GPRS if it is requested by the user.",
    "Unknown.",
    "Registered, roaming.",
};

enum {
    MODEM_CATM = 1,
    MODEM_NB_IOT,
    MODEM_CATM_NBIOT,
};


//!! Set the APN manually. Some operators need to set APN first when registering the network.
//!! Set the APN manually. Some operators need to set APN first when registering the network.
//!! Set the APN manually. Some operators need to set APN first when registering the network.
// Using 7080G with Hologram.io , https://github.com/Xinyuan-LilyGO/LilyGo-T-SIM7080G/issues/19
// const char *apn = "hologram";

const char *apn = "Your APN";
const char gprsUser[] = "";
const char gprsPass[] = "";

// cayenne server address and port
const char server[]   = "mqtt.mydevices.com";
const int  port       = 1883;
char buffer[1024] = {0};

// To create a device : https://cayenne.mydevices.com/cayenne/dashboard
//  1. Add new...
//  2. Device/Widget
//  3. Bring Your Own Thing
//  4. Copy the <MQTT USERNAME> <MQTT PASSWORD> <CLIENT ID> field to the bottom for replacement
char username[] = "<MQTT USERNAME>";
char password[] = "<MQTT PASSWORD>";
char clientID[] = "<CLIENT ID>";

// To create a widget
//  1. Add new...
//  2. Device/Widget
//  3. Custom Widgets
//  4. Button
//  5. Fill in the name and select the newly created equipment
//  6. Channel is filled as 1
//  7. Choose ICON
//  8. Add Widget
int command_channel = 1;


bool isConnect()
{
    modem.sendAT("+SMSTATE?");
    if (modem.waitResponse("+SMSTATE: ")) {
        String res =  modem.stream.readStringUntil('\r');
        return res.toInt();
    }
    return false;
}


void setup()
{

    Serial.begin(115200);

    // Start while waiting for Serial monitoring
    while (!Serial);

    delay(3000);

    Serial.println();

    /*********************************
     *  step 1 : Initialize power chip,
     *  turn on modem and gps antenna power channel
    ***********************************/
    if (!PMU.begin(Wire, AXP2101_SLAVE_ADDRESS, I2C_SDA, I2C_SCL)) {
        Serial.println("Failed to initialize power.....");
        while (1) {
            delay(5000);
        }
    }

    // If it is a power cycle, turn off the modem power. Then restart it
    if (esp_sleep_get_wakeup_cause() == ESP_SLEEP_WAKEUP_UNDEFINED ) {
        PMU.disableDC3();
        // Wait a minute
        delay(200);
    }

    // Set the working voltage of the modem, please do not modify the parameters
    PMU.setDC3Voltage(3000);    // SIM7080 Modem main power channel 2700~ 3400V
    PMU.enableDC3();

    // Modem GPS Power channel
    PMU.setBLDO2Voltage(3300);
    PMU.enableBLDO2();      // The antenna power must be turned on to use the GPS function

    // TS Pin detection must be disable, otherwise it cannot be charged
    PMU.disableTSPinMeasure();


    /*********************************
     * step 2 : start modem
    ***********************************/

    Serial1.begin(115200, SERIAL_8N1, BOARD_MODEM_RXD_PIN, BOARD_MODEM_TXD_PIN);

    pinMode(BOARD_MODEM_PWR_PIN, OUTPUT);
    pinMode(BOARD_MODEM_DTR_PIN, OUTPUT);
    pinMode(BOARD_MODEM_RI_PIN, INPUT);

    int retry = 0;
    while (!modem.testAT(1000)) {
        Serial.print(".");
        if (retry++ > 6) {
            // Pull down PWRKEY for more than 1 second according to manual requirements
            digitalWrite(BOARD_MODEM_PWR_PIN, LOW);
            delay(100);
            digitalWrite(BOARD_MODEM_PWR_PIN, HIGH);
            delay(1000);
            digitalWrite(BOARD_MODEM_PWR_PIN, LOW);
            retry = 0;
            Serial.println("Retry start modem .");
        }
    }
    Serial.println();
    Serial.print("Modem started!");

    /*********************************
     * step 3 : Check if the SIM card is inserted
    ***********************************/
    
    if (modem.getSimStatus() != SIM_READY) {
        Serial.println("SIM Card is not inserted!!!");
        return;
    }

    // Disable RF
    modem.sendAT("+CFUN=0");
    if (modem.waitResponse(20000UL) != 1) {
        Serial.println("Disable RF Failed!");
    }

    /*********************************
     * step 4 : Set the network mode to NB-IOT
    ***********************************/

    modem.setNetworkMode(2);    // use automatic

    modem.setPreferredMode(MODEM_NB_IOT);

    uint8_t pre = modem.getPreferredMode();

    uint8_t mode = modem.getNetworkMode();

    Serial.printf("getNetworkMode:%u getPreferredMode:%u\n", mode, pre);


    // Set the APN manually. Some operators need to set APN first when registering the network.
    modem.sendAT("+CGDCONT=1,\"IP\",\"", apn, "\"");
    if (modem.waitResponse() != 1) {
        Serial.println("Set operators apn Failed!");
        return;
    }

    //!! Set the APN manually. Some operators need to set APN first when registering the network.
    modem.sendAT("+CNCFG=0,1,\"", apn, "\"");
    if (modem.waitResponse() != 1) {
        Serial.println("Config apn Failed!");
        return;
    }

    // Enable RF
    modem.sendAT("+CFUN=1");
    if (modem.waitResponse(20000UL) != 1) {
        Serial.println("Enable RF Failed!");
    }

    /*********************************
    * step 5 : Wait for the network registration to succeed
    ***********************************/
    SIM70xxRegStatus s;
    do {
        s = modem.getRegistrationStatus();
        if (s != REG_OK_HOME && s != REG_OK_ROAMING) {
            Serial.print(".");
            delay(1000);
        }

    } while (s != REG_OK_HOME && s != REG_OK_ROAMING) ;

    Serial.println();
    Serial.print("Network register info:");
    Serial.println(register_info[s]);
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

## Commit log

2023-01-11 Fix not singal loop
    [AllFunction.ino, modem.cpp]
2023-02-16 Added board dwg
    [T-SIM7080G.DXF]
2023-03-31 Fix return value variable types
    [ModemMqttPulishExample.ino, ModemMqttSubscribeExample.ino, ModemMqttsExample.ino]
2023-04-10 Add instructions for using I2C ,fix https://github.com/Xinyuan-LilyGO/LilyGo-T-SIM7080G/issues/6
2023-04-11 Add I2C instructions
2023-05-15 Added shell
    [0-KEY.stl, 0-below.stl, 0-cover.stl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]
2023-05-18 Update shell
    [0-KEY.stl, 0-below.stl, 0-cover.stl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]
2023-05-23 Update wrong PMU name
    [BIGIOT_Gnss_Upload.ino, MinimalCameraExample.ino, MinimalModemGPSExample.ino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]
2023-06-01 Rename to ino, suitable ArduinoIDE.by @bootcampiot
2023-06-05 Added Full sheel,stp
    [0-all_asm.stp]
2024-03-29 Added charge debug example https://github.com/Xinyuan-LilyGO/LilyGo-T-SIM7080G/issues/49
    [MinimalPowersCurrentExample.ino, utilities.h]
2024-03-29 Update schematic https://github.com/Xinyuan-LilyGO/LilyGo-T-SIM7080G/issues/49
2024-05-02 Added Low battery power off examples https://github.com/Xinyuan-LilyGO/LilyGo-T-SIM7080G/issues/64
    [MinimalLowBattPowerOffExample.ino, utilities.h]
2024-07-25 Added Camera test fw
2024-08-21 Added 3D
    [A76XX-3D.stp]
2024-10-09 Fix power startup issues https://github.com/Xinyuan-LilyGO/LilyGo-T-SIM7080G/issues/83
    [ATDebug.ino, BIGIOT_Gnss_Upload.ino, Imagetofiletest.cpp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]
2024-11-26 Added case
    [BatteryHolder.stl]
2025-01-22 Added deep sleep example https://github.com/Xinyuan-LilyGO/LilyGo-T-SIM7080G/issues/98
    [MinimalDeepSleepExample.ino, utilities.h]
2025-02-06 examples: fix register_info type
    [BIGIOT_Gnss_Upload.ino, MinimalModemNBIOTExample.ino, MinimalModemPowerSaveMode.ino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]
2025-02-13 chore: fix step numbers comment
    [MinimalLowBattPowerOffExample.ino, MinimalModemNBIOTExample.ino, MinimalModemSleepMode.ino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]
2025-02-21 Update device video description
2025-03-18 docs: add flat top 18650 battery to README.MD
2025-04-28 Small fixes to MinimalModemGPSExample example
    [MinimalModemGPSExample.ino]
2025-05-13 chore: lint camera.cpp
2025-05-13 chore: lint power.cpp and power.h
2025-05-13 fix: step 3 : Check if the SIM card is inserted
    [BIGIOT_Gnss_Upload.ino, MinimalModemNBIOTExample.ino, MinimalModemPowerSaveMode.ino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]
2025-07-29 fix: incorrect GPRS status
    [MinimalModemSleepMode.ino, ModemMqttPublishExample.ino, ModemMqttSubscribeExample.ino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]
2025-09-16 fix: typo arduino build flags
2025-12-25 Added modem reset example https://github.com/Xinyuan-LilyGO/LilyGo-T-SIM7080G/issues/163#issuecomment-3689530322
    [ModemResetExample.ino, utilities.h]
2026-07-10 Updated 5V connection instructions
2026-08-27 Update deepsleep current note
2026-08-27 Add deepsleep example version print
